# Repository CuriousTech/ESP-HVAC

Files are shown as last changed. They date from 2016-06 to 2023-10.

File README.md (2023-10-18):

# ESP-HVAC (ESP8266 & ESP-32)
WiFi Smart Omniscient HVAC Touchscreen Theromstat  

This project is discontinued (except for bugfixes and support code changes). New work will be on 
[WT32-SC01-HVAC](https://github.com/CuriousTech/WT32-SC01-HVAC)  

<b>2018 Model:</b> The new model was redesigned with a cooler switching regulator (~20mA idle, with a dim screen), smaller ($16.50 from OSHPark) more options for the temp/RH sensor, and the rotory encoder was removed, but has a header for an external encoder or buttons. The only difference in connections is the SCL/SDA were accidentaly reversed on the onboard SHTxx chip. Pics should be at the bottom.  

Notes about the Nextion: The baudrate is bauds=115200 in the main initialize varaibles. This will allow it to communicate at the highest speed.  

The "Basic" (Discovery model works without modification) has a 10K pullduown resistor for 5V tolerance (R13: next to the connector).  Removing this allows the ESP8266 to boot normally and operate without any resistors added, or add a 10K pullup between TX and 3V3 when serial debug is not connected.  I've opted for the removal of the resistor, which fixes all problems.  The 5K6 on the thermostat (R17) allowed it to operate with serial connected plus the pulldown, but not without.  The blue wire (data sent to the ESP) doesn't really need any resistors.  The ESP can't be programmed without a 1K while both are connected, and with the 1K and debug the touchscreen won't work.  So just disconnect the wire while programming and reconnect it after.  

This has replaced the old Spark-O-Stat with a newer system using the ESP-07 (now ESP32), with a better screen (Nextion HMI 2.8" touchscreen), 5 outputs (1 extra output for humidifier), option for SHT21 (I2C) or DHT22/11, AM2302/22, and anolog input for expansion.  

Main and remote units are designed into the single PCB with wired 5V or USB Mini-B for the remote units, and 24VAC for main.  Headers on top are for onboard serial programming of the ESP and Nextion.  Only power it with 1 source at a time. (3V3 for just the ESP, encoder, and temp sensor, 5V to include the display, or 24VAC for all of it including the SSRs). Add the switching regulator to the remote for battery power (6-40V).   

<b>Remote:</b> By tapping the target temperature on the display, it will toggle transmitting the remote temperature and humidity to the main unit to use in all operations.  Tapping the same item on the main unit will also end the remote temperature connection.  There are notifications to indicate use as well as a flashing run indicator instead of solid.  

Some screens including a keyboard and SSID chooser, but this is using the auto connect with SoftAP server (which attempts to find the stored SSID while waiting on input) so it should never be needed.  The dimmed screensaver will change to a clock, and a few other odd displays over time.  

Some display screenshots

Cool/heat low/high:  
These are the desired temperature ranges for cooling and heating, which are calculated based on outside temperature over the next set number of days.  

Cycle:  
Disable heat and cool, but still cycles the fan by the Auto Fan: Run: settings. 4:00 and 5 default = 5 minutes every 4 hours.  

Threshold:  
The temperature offset to complete a cycle.  

Pre-cycle fan time:  
0 disables, 1 second to 5 minutes.  This is the first phase of the cycle.  When the temperature reaches the target, the fan is turned on to cycle air for the set time, which causes the thermostat to read a more overall temperature. If the threshold is reached before this ends, which it can, it will shut off. Otherwise it continues to the run phase, which runs for at least the cycleMin period to save wear on the compressor because this does shorten the run time considerably.  A good value to use is the time it takes to lower the temperature after turning the fan on before it plateaus.  Usually around 2 minutes.  

Post-cycle fan time:  
Runs fan after cycle completes.  This is the third phase of the cycle, which continues to push air through the cold radiator and ductwork.  2 minutes is good, but you can use an IR thermometer on a vent to see how long the cold air continues.  

Humidifier settings:  
Off: Always off  
Fan: Run when fan is on  
Run: Run when thermostat is running a cycle  
Auto1: Operate by humidistat during run cycles  
Auto2: Humidistat runs indepentantly of thermostat (shares fan control)  

Override:  
Use to heat or cool by a selected offset temperature for a specified time.  

Freshen:  
Starts the fan with a timeout.  This uses the post fan timer, so a normal cycle will cancel it.  

Idle min, cycle min/max:  
These are timers in seconds to control the thermstat operating limits.  Idle min is the shortest time between cycles.  Cycle min is the shortest time for a cycle, and max is the longest.  Be careful with these settings.  Running the compressor too short or too long can cause damage.  

Away time and temperature delta offset:  
The away time is in hours:minutes unlike the rest of the timers, but uses the override timer.  It can be turned on and off with the button, but will also turn off with the timer.  There are 2 temp values that are displayed depending on heat or cool mode.  One for heat and one for cool, like the pre/post fan.
Like any setting, it can be automated with something like Tasker.  To turn on would be <b>http://ip:85?key=password&away=1</b>  

Other settings:  
AC differential limit: Increases thermostat if inside/outside difference is more than 30. This assumes Fahrenheit. Change for Celcius.  
Heat Threshold: Heatpump will switch off and use gas when outside temp goes below set value (default 33). Change for Celcius.  
PKW (price per killawatt hour), CFM (gas cubic feet per minute), CCF (cost per 100 cubic foot): Set the PPKW and CCF based on billing. CFM is dependant on the furnace.  
FC Shift (in minutes): Shifts the forecast for the temperature adjust. Use the setting on the chart page (they don't affect the actual settings) to determine what's best. There are 2 values for heat and cool here as well.   

remotepage  

The web chart.  Dark gray is off, cyan is fan running, blue is compressor+fan, NG is red, HP is yellow, rh is green, the target/threshold is the wave.  The thermostat is in the hottest room in the house, so it does look warmer than it really is, but that's why there's a remote unit, and now multiple sensors.  
chartpage  

dualstats  

New Model
model2  
Remote (this uses only a few components: the 3.3V regulator, 3 capacitors, USB connector, temp sensor, and 7 required resistors)  
model2rem  
model2side  

Sensor web page  
envmon

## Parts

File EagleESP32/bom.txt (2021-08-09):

PCB OSHPark $17.55 for 3

ESP-32        eBay
USB Micro-B   ZX62D-B-5PA8(30) or common eBay (remote only)
Nextion HMI   2.8" eBay
3V3R          MCP1755T-3302E/OT or MCP1802T-3302
TXRX,LCD      0.1" headers. Use for serial programming ESP, debug, Nextion.

rh/temp sensor options:
 AM2320      (larger 4 pin, i2c)
 AM2322      (lower 4 pin, i2c)
 SHT21       DFN-6
 Si7021      cheaper DFN-6
 Si7034      super cheap

R1-R5     *  0805 470 (390 lowest)
R7        *  0805 470
R8,R9        0805 10K
R10,R11      0805 4K7
R12          0805 10K (pullup in case 10K isn't removed from Nextion)
R13,R15      0805 1K
R14          0805 5K1

F1        *  1812 PPTC Fuse 1.5A PTS181224V150
BR        *  MDB6S
VREG      *  LMR16006YQ5DDCRQ1
L1        *  0805 6.8uH IFSC0806AZER6R8M01
D1,D2    (*) SOT-223 NSVR0320MW2T1G
C1 or C2  *  10uF+ 25V+ 5mm (25SEPF56M 56uF throughole)
C3-C6     *  0805 16V 0.1uF
C7        *  0805 16V 1uF
C8        *  0805 16V 10uF
C9           0603 16V 0.1uF (if SHTxx used)
C10       *  0805 2.2uF

Q1           PMV20ENR (for future speaker)
SPK          20mm-36mm 32 ohm speaker
K1-K5     *  G3VM-61GR2
X1        *  39357-0008 (or 691322110008 and 691361100008) Screw terimal, 8 position 3.5mm pitch
Button       TL1014BF160QG

* Only for main controller

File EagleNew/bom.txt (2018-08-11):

PCB OSHPark $16.50 for 3

ESP-07          eBay
USB Micro-B     ZX62D-B-5PA8(30) or common eBay (remote only)
Nextion HMI     2.8" eBay
3V3R            MCP1755T-3302E/OT
TXRX,LCD,DHT    0.1" headers. Use for serial programming ESP, debug, Nextion.

rh/temp sensor options:
 AM2302/DHT22   (upper 4 pin)
 AM2320         (lower 4 pin, i2c)
 SHT21          DFN-6
 Si7021         cheaper DFN-6
 Si7034         super cheap

R1-R5       *   0805 470
R6-R8       *   0805 10K
R9              0805 10K (use R9 on remote as well)
R10,R11         0805 10K
R12,R13         0805 4K7 (ignore for AM2302)
R14,R15         ADC voltage divider (not used)
R16,R17         0805 5K6
R19             0805 10K (pullup in case 10K isn't removed from Nextion)
R20         *   0805 4K7

F1          *   1812 PPTC Fuse 1.5A PTS181224V150
BR          *   MDB10SV
VREG        *   LMR16006YQ5DDCRQ1
L1          *   0805 6.8uH IFSC0806AZER6R8M01
D1          *   SOT-223 NSVR0320MW2T1G
C1 or C2    *   10uF+ 25V+ 5mm (PCV1E470MCL2GS 6mm) or UZR1V100MCL1GB
C3-C6       *   0805 16V 0.1uF
C7          *   0805 16V 1uF
C8          *   0805 16V 10uF
C9              0603 16V 0.1uF (if SHTxx used)
C10         *   0805 2.2uF

K1-K5       *   G3VM-61GR2 (stays cooler), or AQY282S, or any SMD-DIP4 1FormA 30VAC+ 500mA~5A
X1          *   39357-0008 (or 691322110008 and 691361100008) Screw terimal, 8 position 3.5mm pitch
J1              ADC expansion (Not used)

* Only for main controller

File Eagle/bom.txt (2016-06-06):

ESP-07          eBay
USB Mini-B      Only use for powering remote unit with wall adapter
Nextion HMI     2.8" eBay
AM2302/DHT22    Don't use with SHT21
SHT21           Don't use with DHT22
R1-R5       *   0805 470
R6-R9       *   0805 10K (do not remove R9 - GPIO15 must be low on boot)
R10,R11         0805 10K
R12,R13         0805 4K7
R14,R15         ADC voltage divider (not used)
R16,R17         5K6
R18             0 jumper (Do not use: Allows for I2C device in place of DHT22)
R19             10K 0805 (pullup in case 10K isn't removed from Nextion)
R20         *   4K7 0805
C1          *   UWD1V150MCL1 35V 15uF
C2          *   UCL1A221MCL1GS 10V 220uF
C3,C4           0805 16V 0.1uF
C5,C6           0805 10V 0.01uF
C7,C8           0805 16V 1uF
C9              0805 16V 0.1uF
F1          *   1812 PPTC Fuse 1.5A PTS181224V150
LCD,NEXPROG     4-pin 0.1" header.  Same pinout.  Use either for serial programming of display.
J1              ADC expansion.  Not used.
PIC10F      *   Not used.  Watchdog connected to SCL for monitor, RESET output.
5VSWPP      *   MIC4680-5.0YM
3V3R            MCP1755T-3302E/OT
L1          *   SRU1048-680Y
K1-K5       *   AQY282SZ or AQY282S (3 main, 1 for HP, 1 for humidifier)
B1          *   DF206S-G
D1          *   B260A-13-F
X1          *   39357-0008 Screw terimal, 8 position 3.5mm pitch
Encoder         EC12E24204A2 or other 12mm short shaft
Q1          *   MMBT2907ALT1G (general purpose BJT PNP) GPIO0 must be high or Z on boot.
PRG,TXRX        2-pin headers.  Use for serial programming ESP, debug, Nextion simulator.

* Only for main controller

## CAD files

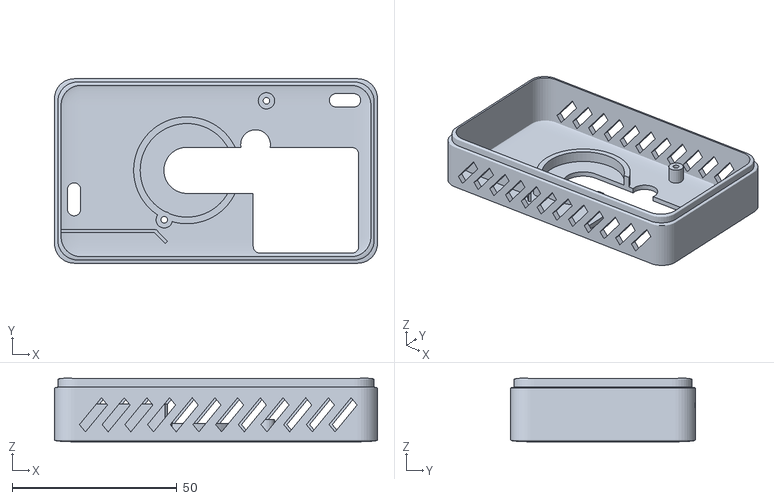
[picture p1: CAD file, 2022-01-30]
3D/ThermostatBack_SHT21.stl
98.0 x 56.0 x 19.3

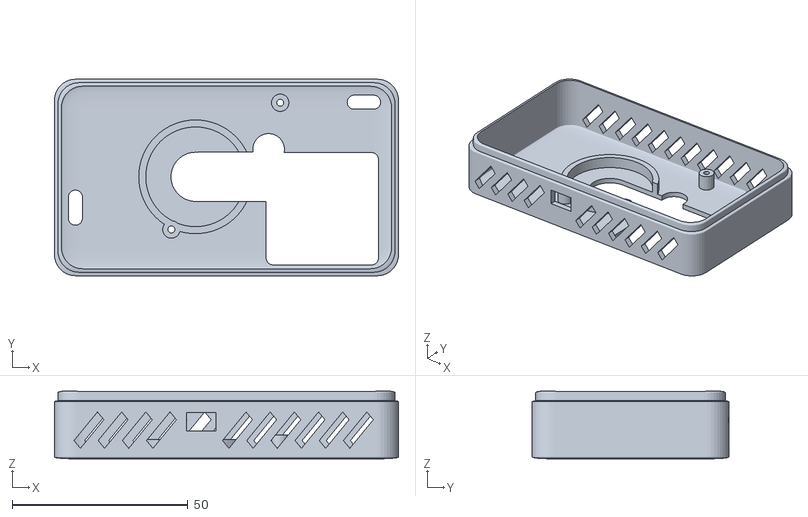
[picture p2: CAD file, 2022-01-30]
3D/ThermostatBack_AM2322.stl
98.0 x 56.0 x 19.3

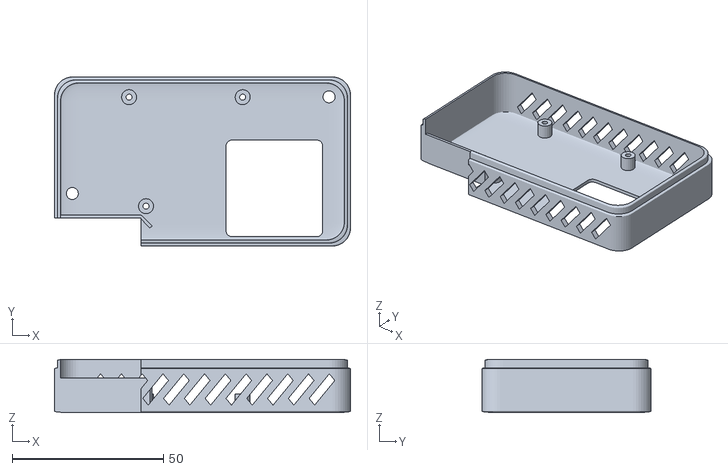
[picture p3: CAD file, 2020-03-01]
3D/BackM2.stl
98.0 x 56.0 x 17.6

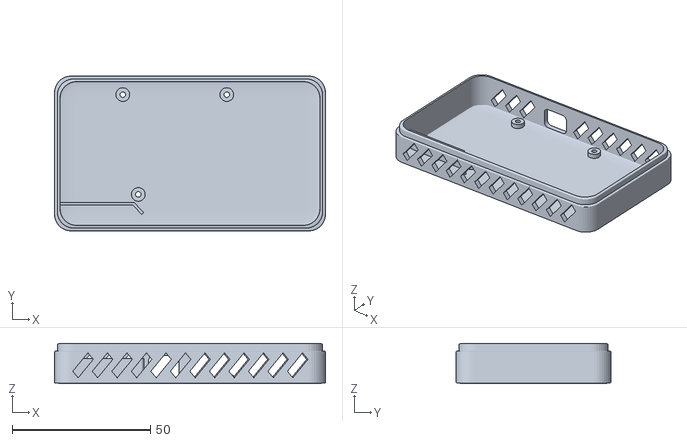
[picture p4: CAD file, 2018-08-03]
3D/RmtBackM2.stl
98.0 x 56.0 x 14.5

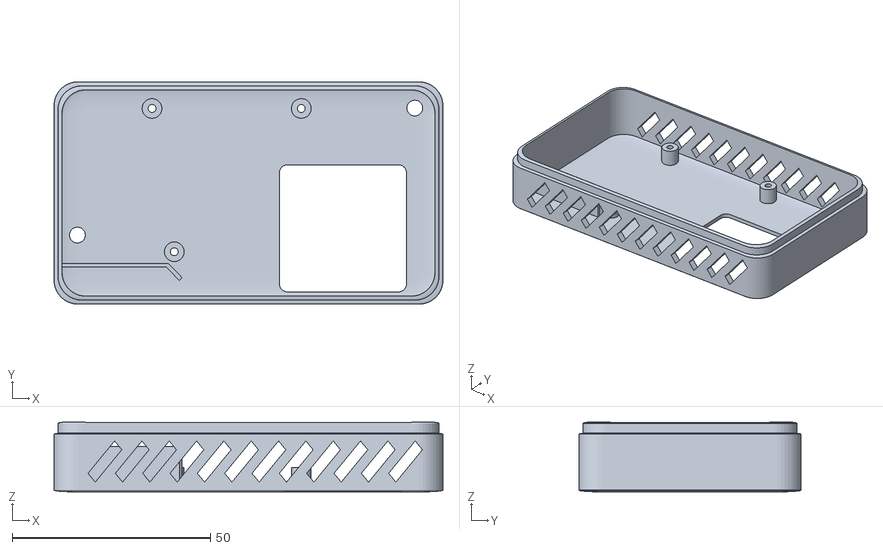
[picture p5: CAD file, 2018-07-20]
3D/BackDeepM2.stl
98.0 x 56.0 x 17.6

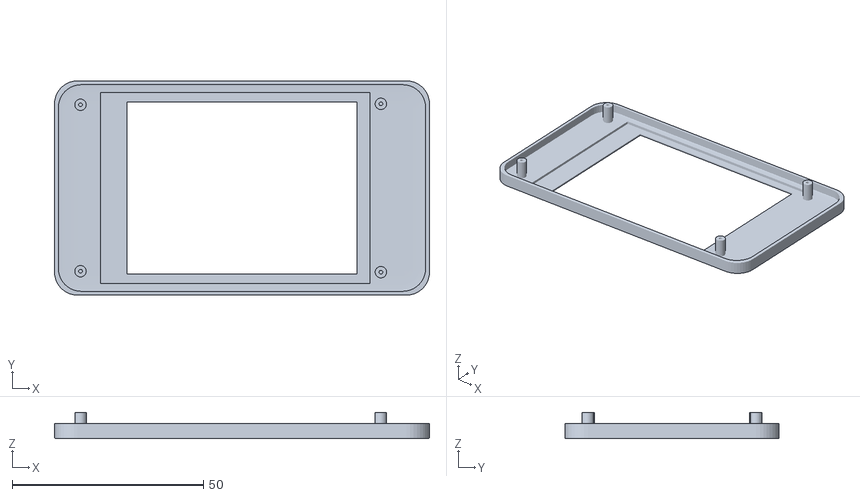
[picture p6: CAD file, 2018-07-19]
3D/FaceplateM2.stl
98.0 x 56.0 x 6.86

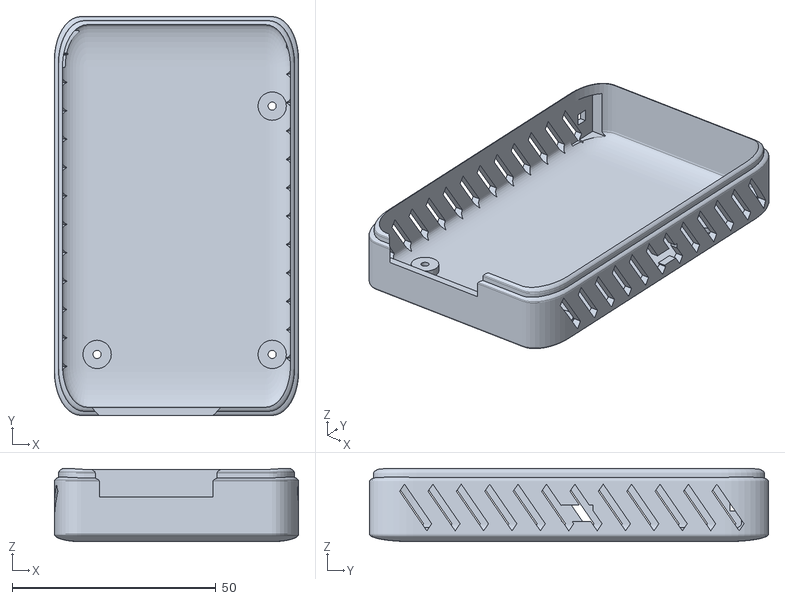
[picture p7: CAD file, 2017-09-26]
3D/Remote back.stl
60.0 x 98.0 x 18.0

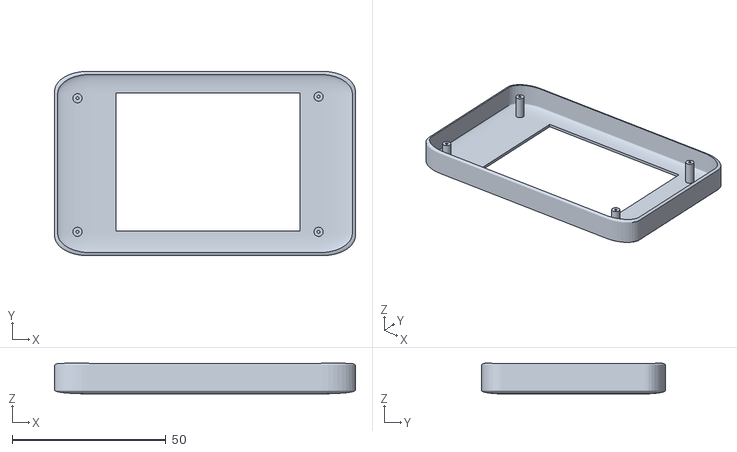
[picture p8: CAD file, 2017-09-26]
3D/Faceplate.stl
98.0 x 60.0 x 9.99

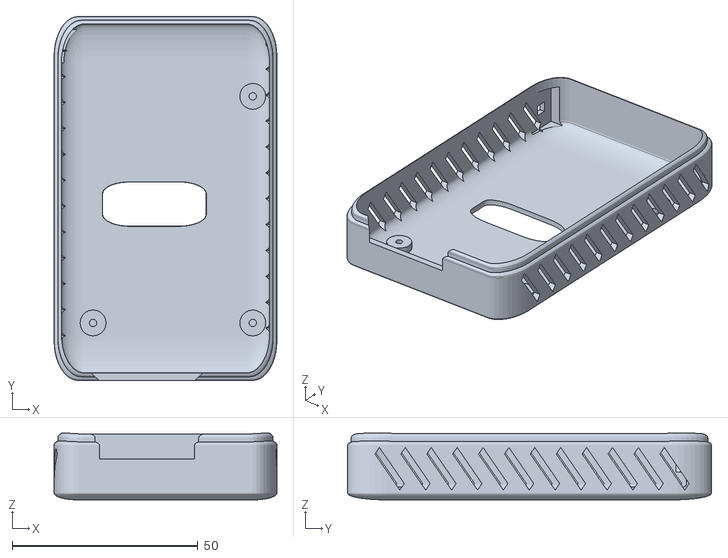
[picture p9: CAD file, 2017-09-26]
3D/Thermostat back.stl
60.0 x 98.0 x 18.0

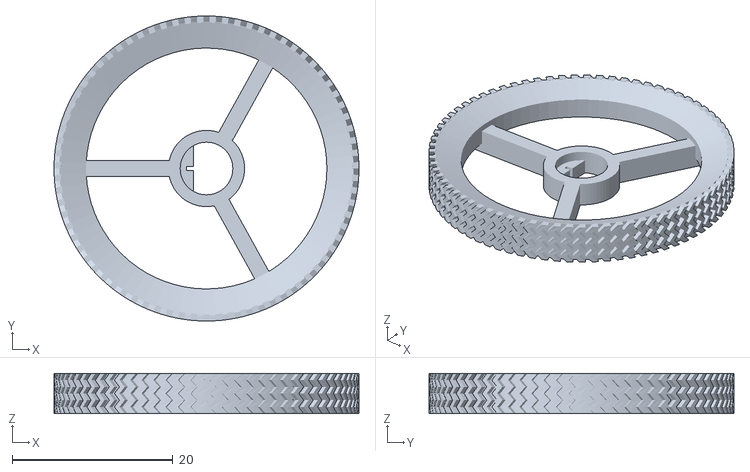
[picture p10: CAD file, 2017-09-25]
3D/Encoder Wheel.stl
38.0 x 38.0 x 5.00

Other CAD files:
3D/ThermostatBack_AM2302.stl
3D/ThermostatBack_AM2320.stl

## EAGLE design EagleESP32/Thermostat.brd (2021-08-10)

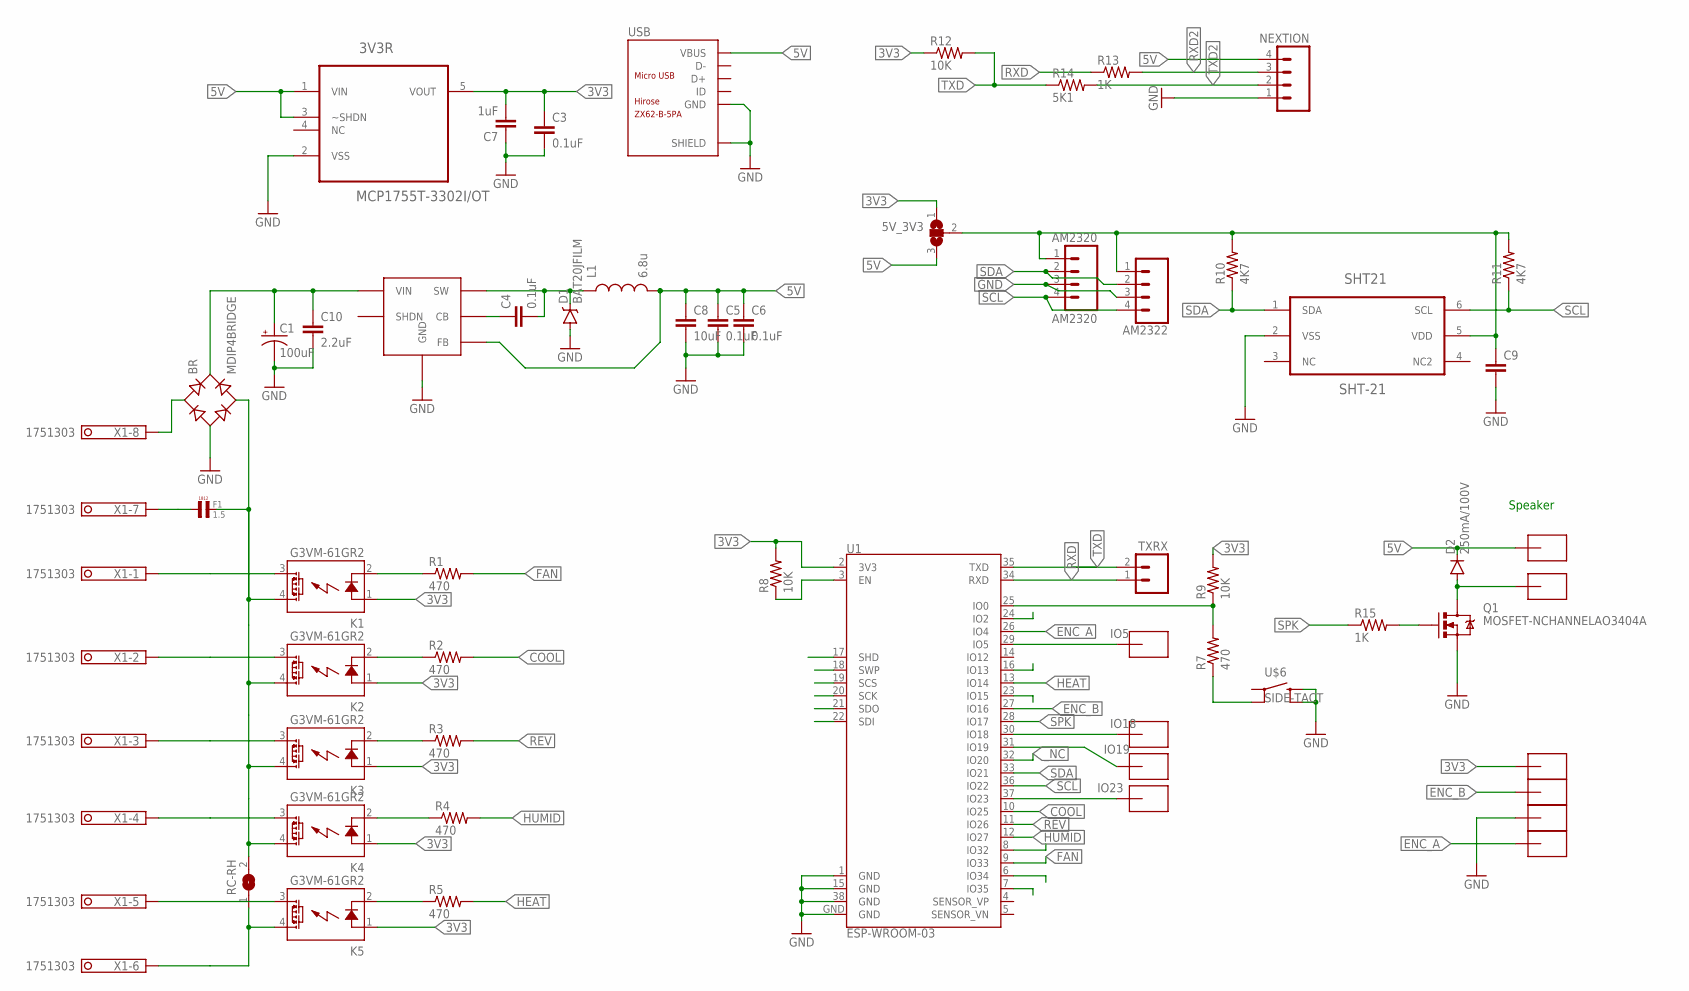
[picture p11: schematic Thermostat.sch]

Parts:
3V3R: MCP1755T-3302I/OT; SOT95P270X145-5N
5V_3V3: SJ2W; SJ_2
AM2320: AM2320; 1X04
AM2322: CONN_041.27MM; 1X04_1.27MM
BR: MDIP4BRIDGE; MICRODIP4
C1: 100uF; PANASONIC_C
C3, C4, C5, C6: 0.1uF; 0805
C7: 1uF; 0805
C8: 10uF; 0805
C9: CAP0603-CAP; 0603-CAP
C10: 2.2uF; 0805
D1: BAT20JFILM; SOD-323
D2: 250mA/100V; SOD-323
F1: 1.5; L4,8
K1, K2, K3, K4, K5: G3VM-61GR2; SOP04
L1: 6.8u; 1007
NEXTION: M04PTH; 1X04
Q1: MOSFET-NCHANNELAO3404A; SOT23-3
R1, R2, R3, R4, R5, R7: 470; 0805
R8, R9, R12: 10K; 0805
R10, R11: 4K7; 0805
R13, R15: 1K; 0805
R14: 5K1; 0805
RC-RH: SJ
SHT21: SHT-21; SHT21
TXRX: M02PTH; 1X02
U1: ESP-WROOM-03
U$1, U$2, U$3, U$4: SMD-PAD182X64; SMD-PAD1
U$5, U$7, U$8, U$9, U$10, U$11: SMD-PAD1SMD-PAD80X32; SMD-PAD6
U$6: SIDE-TACT
USB: ZX62-B-5PA; MICRO-USB5+6P-SMD-0.65-AB
VREG: LMR16006YQ; SOT-23-6
X1: 1751303

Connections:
3V3: 3V3R.5 (VOUT), 5V_3V3.1, C3.1, C7.2, K1.1 (A), K2.1 (A), K3.1 (A), K4.1 (A), K5.1 (A), R8.2, R9.2, R12.1, U1.2 (3V3), U$7.>PAD
5V: 3V3R.1 (VIN), 3V3R.3 (~SHDN), 5V_3V3.3, C5.1, C6.1, C8.1, D2.C, L1.2, NEXTION.4, U$5.>PAD, USB.1 (VBUS), VREG.3 (FB)
COOL: R2.2, U1.10 (IO25)
ENC_A: U1.26 (IO4), U$10.>PAD
ENC_B: U1.27 (IO16), U$8.>PAD
FAN: R1.2, U1.9 (IO33)
GND: 3V3R.2 (VSS), AM2320.3, AM2322.3, BR.-, C1.-, C3.2, C5.2, C6.2, C7.1, C8.2, C9.2, C10.2, D1.A, NEXTION.1, Q1.2 (S), SHT21.2 (VSS), U1.1 (GND), U1.15 (GND), U1.38 (GND), U1.GND, U$6.3 (2), U$6.4, U$9.>PAD, USB.5 (GND), USB.P1 (SHIELD), USB.P2 (SHIELD), USB.P3 (SHIELD), USB.P4 (SHIELD), USB.P5 (SHIELD), USB.P6 (SHIELD), VREG.2 (GND)
HEAT: R5.2, U1.13 (IO14)
HUMID: R4.2, U1.12 (IO27)
IO5: U1.29 (IO5), U$3.>PAD
IO18: U1.30 (IO18), U$4.>PAD
IO19: U1.31 (IO19), U$1.>PAD
IO23: U1.37 (IO23), U$2.>PAD
unnamed: C4.2, D1.C, L1.1, VREG.6 (SW)
unnamed: BR.AC2, F1.P$2 (2), K1.4 (DS1), K2.4 (DS1), K3.4 (DS1), K4.4 (DS1), RC-RH.2
unnamed: K4.2 (K), R4.1
unnamed: Q1.1 (G), R15.2
unnamed: K3.2 (K), R3.1
unnamed: R8.1, U1.3 (EN)
unnamed: K2.2 (K), R2.1
unnamed: K4.3 (DS2), X1.4
unnamed: K2.3 (DS2), X1.2
unnamed: R7.2, R9.1, U1.25 (IO0)
unnamed: K1.3 (DS2), X1.1
unnamed: K1.2 (K), R1.1
unnamed: C4.1, VREG.1 (CB)
unnamed: K5.3 (DS2), X1.5
unnamed: BR.AC1, X1.8
unnamed: K5.4 (DS1), RC-RH.1, X1.6
unnamed: F1.P$1 (1), X1.7
unnamed: BR.+, C1.+, C10.1, VREG.5 (VIN)
unnamed: K5.2 (K), R5.1
unnamed: R7.1, U$6.2 (3)
unnamed: K3.3 (DS2), X1.3
unnamed: D2.A, Q1.3 (D), U$11.>PAD
NC: SHT21.3 (NC)
PWR: 5V_3V3.2, AM2320.1, AM2322.1, C9.1, R10.2, R11.2, SHT21.5 (VDD)
REV: R3.2, U1.11 (IO26)
RXD: R13.1, TXRX.1, U1.34 (RXD)
RXD2: NEXTION.3, R13.2
SCL: AM2320.4, AM2322.4, R11.1, SHT21.6 (SCL), U1.36 (IO22)
SDA: AM2320.2, AM2322.2, R10.1, SHT21.1 (SDA), U1.33 (IO21)
SPK: R15.1, U1.28 (IO17)
TXD: R12.2, R14.1, TXRX.2, U1.35 (TXD)
TXD2: NEXTION.2, R14.2
_NC: U1.32 (IO20)

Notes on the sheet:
Speaker

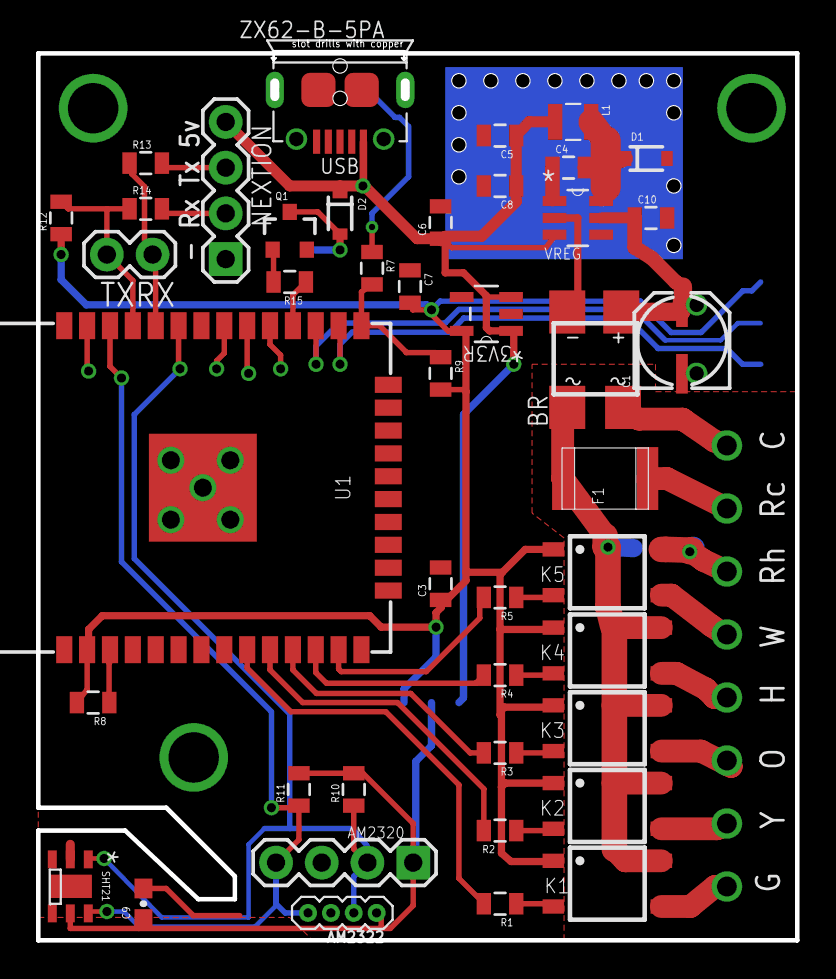
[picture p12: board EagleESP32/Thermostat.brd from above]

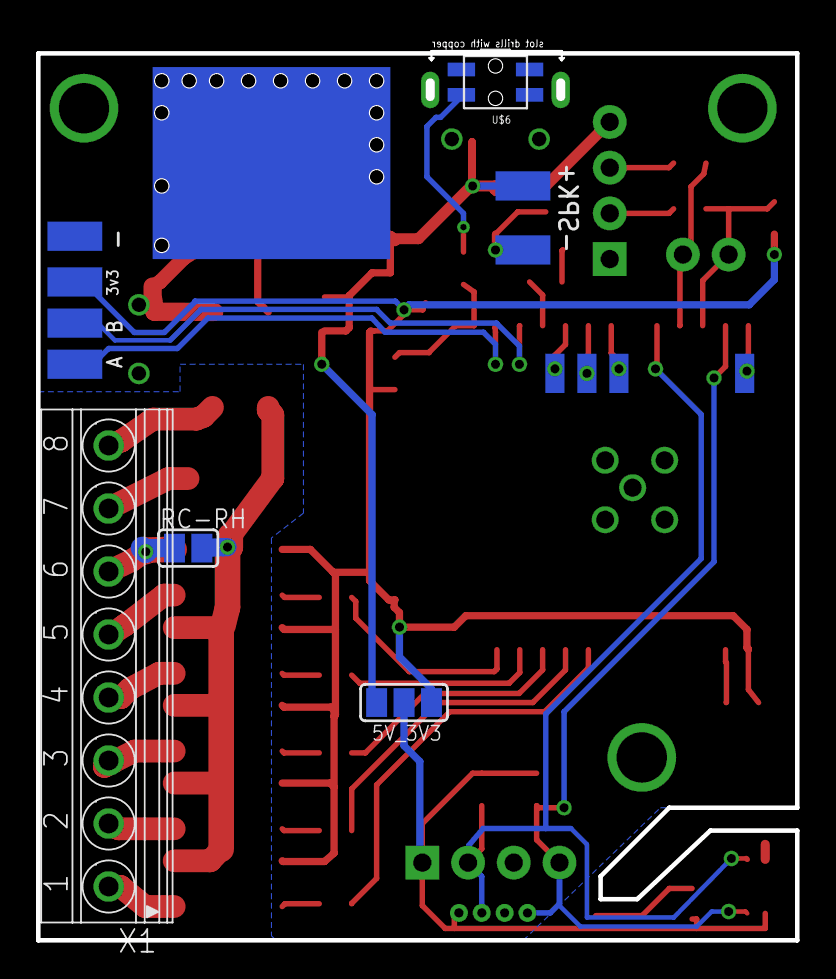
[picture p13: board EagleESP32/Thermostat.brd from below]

Board: 2 copper layers, 42.2 x 49.3 mm, 57 parts (14 on the bottom side), 44 nets.

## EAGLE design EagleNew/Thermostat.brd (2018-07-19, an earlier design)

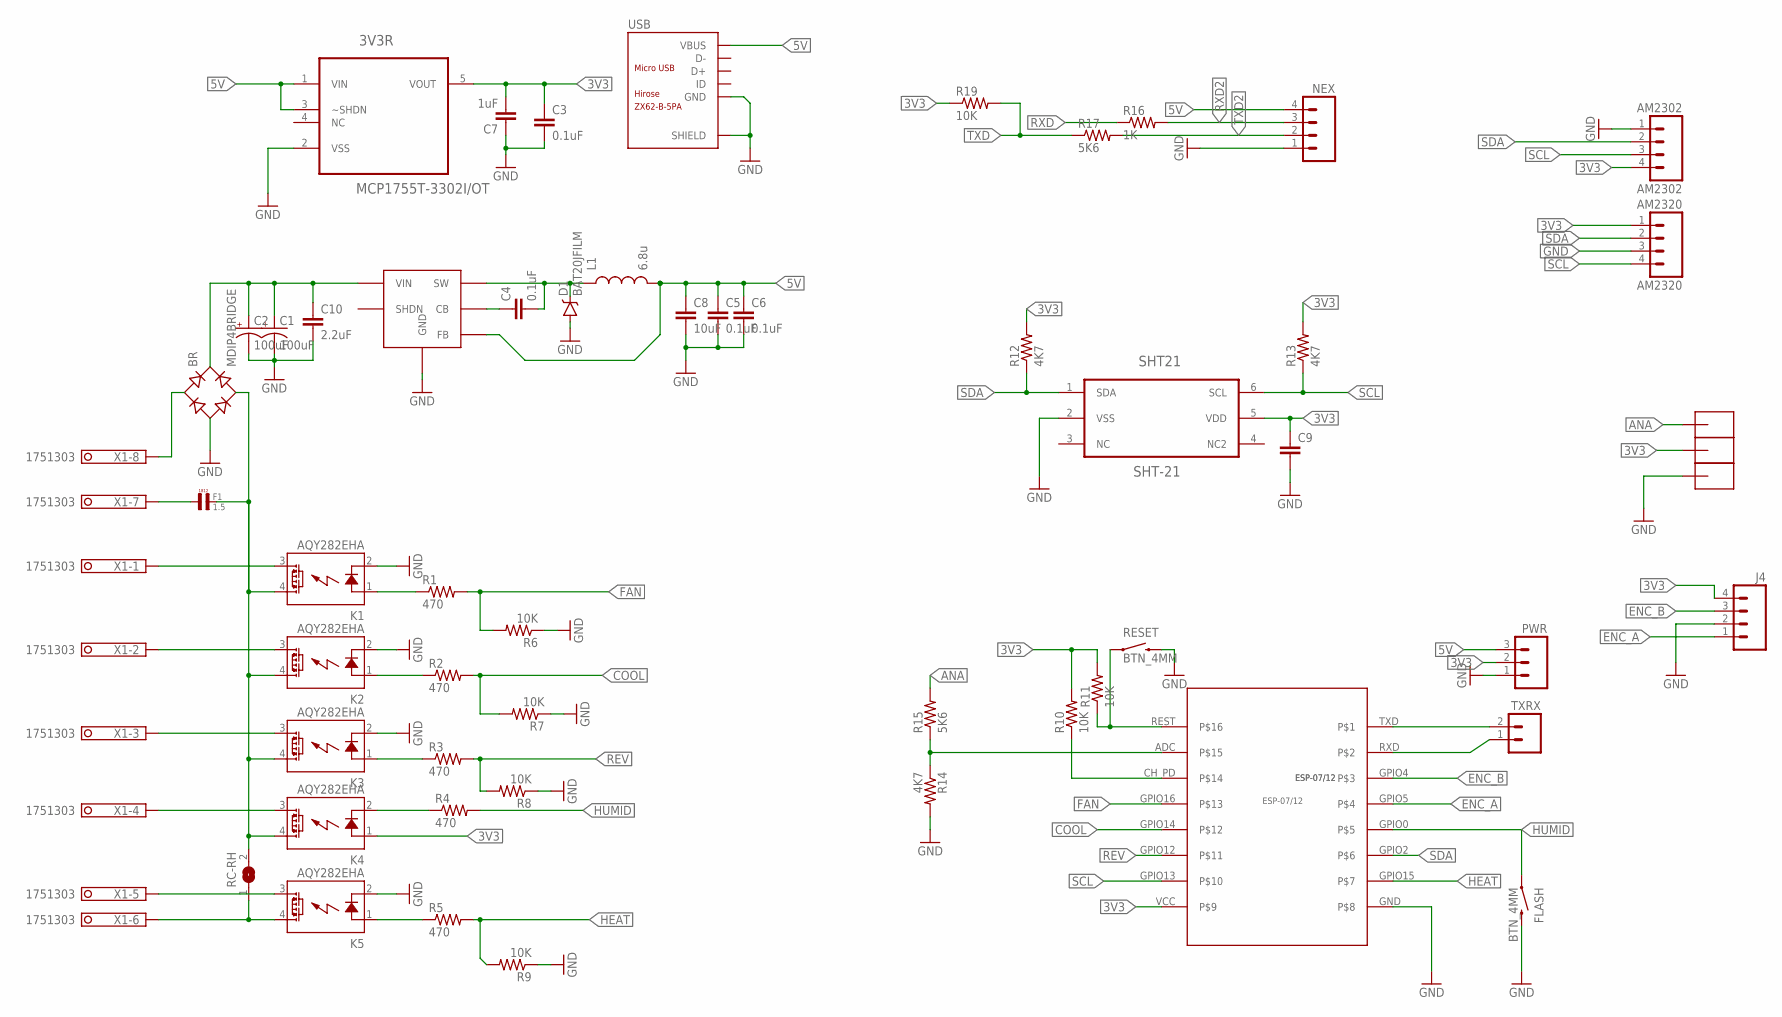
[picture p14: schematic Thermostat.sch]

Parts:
3V3R: MCP1755T-3302I/OT; SOT95P270X145-5N
AM2302: AM2302; 1X04
AM2320: AM2320; 1X04
BR: MDIP4BRIDGE; MICRODIP4
C1, C2: 100uF; PANASONIC_C
C3, C4, C5, C6: 0.1uF; 0805
C7: 1uF; 0805
C8: 10uF; 0805
C9: CAP0603-CAP; 0603-CAP
C10: 2.2uF; 0805
D1: BAT20JFILM; SOD-323
F1: 1.5; L4,8
FLASH: BTN_4MM
J4: M04PTH; 1X04
K1, K2, K3, K4, K5: AQY282EHA; SOP04
L1: 6.8u; 1007
NEX: M04PTH; 1X04
PWR: M03PTH; 1X03
R1, R2, R3, R4, R5: 470; 0805
R6, R7, R8, R9, R10, R11, R19: 10K; 0805
R12, R13, R14: 4K7; 0805
R15, R17: 5K6; 0805
R16: 1K; 0805
RC-RH: SJ
RESET: BTN_4MM
SHT21: SHT-21; SHT21
TXRX: M02PTH; 1X02
U$1: ESP-07/12
U$2, U$3, U$4: SMD-PAD182X64; SMD-PAD1
USB: ZX62-B-5PA; MICRO-USB5+6P-SMD-0.65-AB
VREG: LMR16006YQ; SOT-23-6
X1: 1751303

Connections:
3V3: 3V3R.5 (VOUT), AM2302.4, AM2320.1, C3.1, C7.2, C9.1, J4.4, K4.1 (A), PWR.2, R10.2, R11.2, R12.2, R13.2, R19.1, SHT21.5 (VDD), U$1.VCC, U$3.>PAD
5V: 3V3R.1 (VIN), 3V3R.3 (~SHDN), C5.1, C6.1, C8.1, L1.2, NEX.4, PWR.3, USB.1 (VBUS), VREG.3 (FB)
ADC: R14.1, R15.1, U$1.ADC
ANA: R15.2, U$4.>PAD
COOL: R2.2, R7.2, U$1.GPIO14
ENC_A: J4.1, U$1.GPIO5
ENC_B: J4.3, U$1.GPIO4
FAN: R1.2, R6.2, U$1.GPIO16
GND: 3V3R.2 (VSS), AM2302.1, AM2320.3, BR.-, C1.-, C2.-, C3.2, C5.2, C6.2, C7.1, C8.2, C9.2, C10.2, D1.A, FLASH.2, J4.2, K1.2 (K), K2.2 (K), K3.2 (K), K5.2 (K), NEX.1, PWR.1, R6.1, R7.1, R8.1, R9.1, R14.2, RESET.2, SHT21.2 (VSS), U$1.GND, U$2.>PAD, USB.5 (GND), USB.P1 (SHIELD), USB.P2 (SHIELD), USB.P3 (SHIELD), USB.P4 (SHIELD), USB.P5 (SHIELD), USB.P6 (SHIELD), VREG.2 (GND)
HEAT: R5.2, R9.2, U$1.GPIO15
HUMID: FLASH.1, R4.2, U$1.GPIO0
unnamed: K4.2 (K), R4.1
unnamed: C4.2, D1.C, L1.1, VREG.6 (SW)
unnamed: BR.AC2, F1.P$2 (2), K1.4 (DS1), K2.4 (DS1), K3.4 (DS1), K4.4 (DS1), RC-RH.2
unnamed: K1.1 (A), R1.1
unnamed: K2.1 (A), R2.1
unnamed: K3.1 (A), R3.1
unnamed: K4.3 (DS2), X1.4
unnamed: K2.3 (DS2), X1.2
unnamed: K1.3 (DS2), X1.1
unnamed: C4.1, VREG.1 (CB)
unnamed: K5.3 (DS2), X1.5
unnamed: BR.AC1, X1.8
unnamed: K5.4 (DS1), RC-RH.1, X1.6
unnamed: F1.P$1 (1), X1.7
unnamed: BR.+, C1.+, C2.+, C10.1, VREG.5 (VIN)
unnamed: K5.1 (A), R5.1
unnamed: K3.3 (DS2), X1.3
unnamed: R10.1, U$1.CH_PD
NC: SHT21.3 (NC)
REST: R11.1, RESET.1, U$1.REST
REV: R3.2, R8.2, U$1.GPIO12
RXD: R16.1, TXRX.1, U$1.RXD
RXD2: NEX.3, R16.2
SCL: AM2302.3, AM2320.4, R13.1, SHT21.6 (SCL), U$1.GPIO13
SDA: AM2302.2, AM2320.2, R12.1, SHT21.1 (SDA), U$1.GPIO2
TXD: R17.1, R19.2, TXRX.2, U$1.TXD
TXD2: NEX.2, R17.2

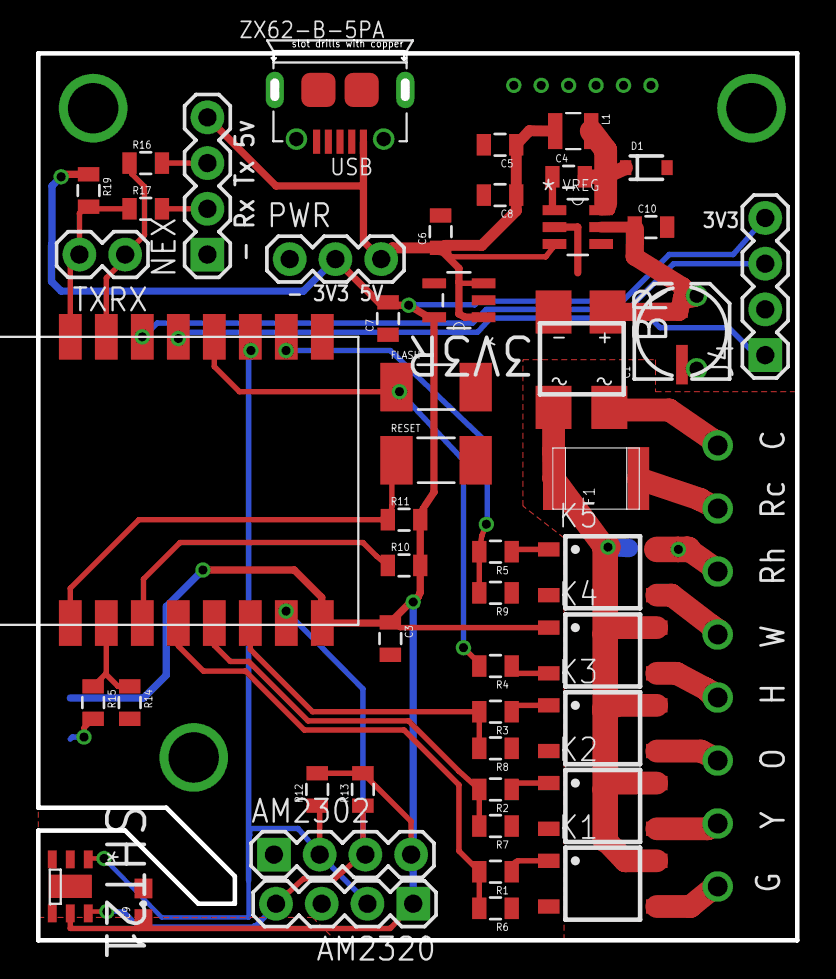
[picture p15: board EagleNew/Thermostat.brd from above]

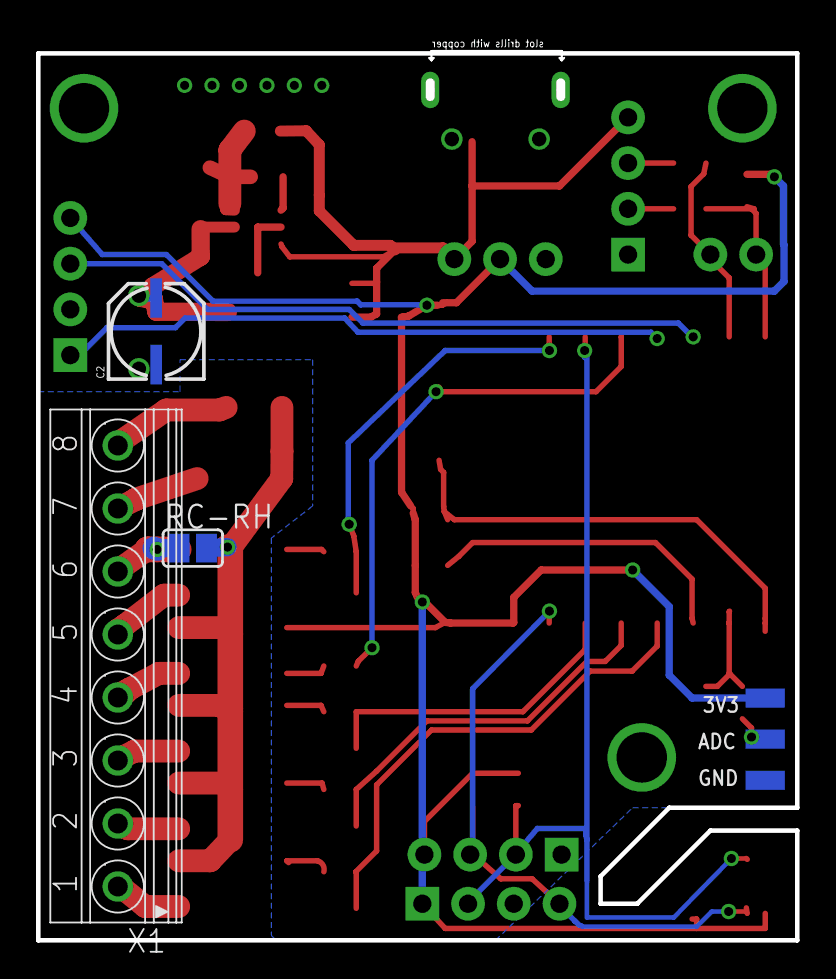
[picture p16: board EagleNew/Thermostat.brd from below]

Board: 2 copper layers, 42.2 x 49.3 mm, 55 parts (6 on the bottom side), 37 nets.

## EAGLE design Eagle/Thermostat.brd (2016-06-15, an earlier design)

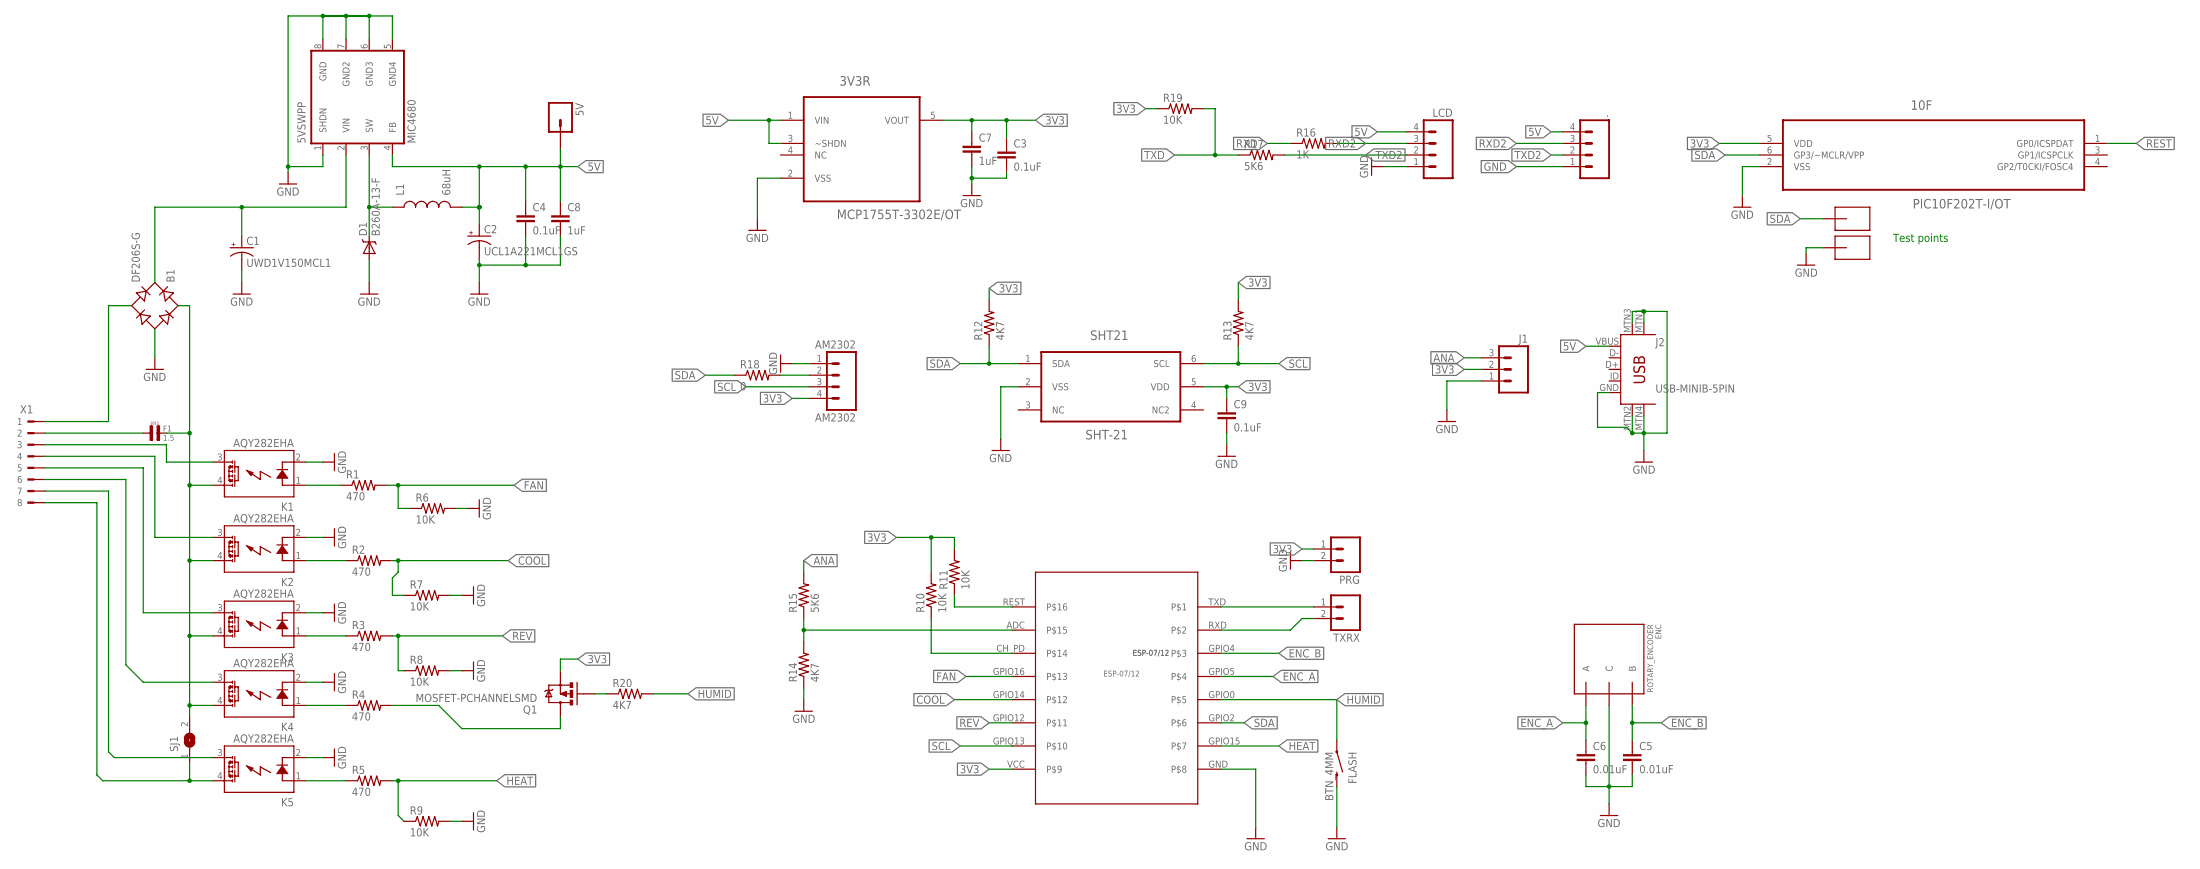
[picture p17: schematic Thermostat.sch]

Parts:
3V3R: MCP1755T-3302E/OT; SOT95P270X145-5N
5V: M01PTH; 1X01
5VSWPP: MIC4680; SO08
10F: PIC10F202T-I/OT; SOT95P270X145-6N
.: M04PTH; 1X04
AM2302: AM2302; 1X04
B1: DF206S-G; DFS
C1: UWD1V150MCL1; PANASONIC_C
C2: UCL1A221MCL1GS; PANASONIC_D
C3, C4, C9: 0.1uF; 0805
C5, C6: 0.01uF; 0805
C7, C8: 1uF; 0805
D1: B260A-13-F; SMA-DIODE
ENC: ROTARY_ENCODER; ROTORY_ENC
F1: 1.5; L4,8
FLASH: BTN_4MM
J1: M03PTH; 1X03
J2: USB-MINIB-5PIN; USB-MINIB
K1, K2, K3, K4, K5: AQY282EHA; SOP04
L1: 68uH; DR1030
LCD: M04PTH; 1X04
PRG: M02PTH; 1X02
Q1: MOSFET-PCHANNELSMD; SOT23-3
R1, R2, R3, R4, R5: 470; 0805
R6, R7, R8, R9, R10, R11, R19: 10K; 0805
R12, R13, R14, R20: 4K7; 0805
R15, R17: 5K6; 0805
R16: 1K; 0805
R18: 0; 0805
SHT21: SHT-21; SHT21
SJ1: SJ
TXRX: M02PTH; 1X02
U$1: ESP-07/12
U$2, U$5: SMD-PAD1
X1: 180-8

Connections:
3V3: 3V3R.5 (VOUT), 10F.5 (VDD), AM2302.4, C3.1, C7.1, C9.1, J1.2, PRG.1, Q1.2 (S), R10.2, R11.2, R12.2, R13.2, R19.1, SHT21.5 (VDD), U$1.VCC
5V: 3V3R.1 (VIN), 3V3R.3 (~SHDN), 5V.1, 5VSWPP.4 (FB), ..4, C2.+, C4.1, C8.1, J2.VBUS, L1.2, LCD.4
ADC: R14.2, R15.1, U$1.ADC
ANA: J1.3, R15.2
COOL: R2.2, R7.1, U$1.GPIO14
ENC_A: C6.1, ENC.A, U$1.GPIO5
ENC_B: C5.1, ENC.B, U$1.GPIO4
FAN: R1.2, R6.1, U$1.GPIO16
GND: 3V3R.2 (VSS), 5VSWPP.1 (SHDN), 5VSWPP.5 (GND4), 5VSWPP.6 (GND3), 5VSWPP.7 (GND2), 5VSWPP.8 (GND), 10F.2 (VSS), ..1, AM2302.1, B1.-, C1.-, C2.-, C3.2, C4.2, C5.2, C6.2, C7.2, C8.2, C9.2, D1.A, ENC.C, FLASH.2, J1.1, J2.GND, J2.MTN1 (MTN2), J2.MTN2 (MTN3), J2.MTN3 (MTN1), J2.MTN4, K1.2 (K), K2.2 (K), K3.2 (K), K4.2 (K), K5.2 (K), LCD.1, PRG.2, R6.2, R7.2, R8.2, R9.2, R14.1, SHT21.2 (VSS), U$1.GND, U$2.>NAME
HEAT: R5.2, R9.1, U$1.GPIO15
HUMID: FLASH.1, R20.2, U$1.GPIO0
unnamed: Q1.1 (G), R20.1
unnamed: 5VSWPP.3 (SW), D1.C, L1.1
unnamed: B1.AC1, F1.P$2 (2), K1.4 (DS1), K2.4 (DS1), K3.4 (DS1), K4.4 (DS1), SJ1.2
unnamed: K1.1 (A), R1.1
unnamed: K2.1 (A), R2.1
unnamed: Q1.3 (D), R4.2
unnamed: K3.1 (A), R3.1
unnamed: K4.3 (DS2), X1.6
unnamed: K2.3 (DS2), X1.4
unnamed: K4.1 (A), R4.1
unnamed: K1.3 (DS2), X1.3
unnamed: AM2302.2, R18.2
unnamed: K5.3 (DS2), X1.7
unnamed: B1.AC2, X1.1
unnamed: 5VSWPP.2 (VIN), B1.+, C1.+
unnamed: K5.1 (A), R5.1
unnamed: K5.4 (DS1), SJ1.1, X1.8
unnamed: K3.3 (DS2), X1.5
unnamed: R10.1, U$1.CH_PD
unnamed: F1.P$1 (1), X1.2
NC: SHT21.3 (NC)
REST: 10F.1 (GP0/ICSPDAT), R11.1, U$1.REST
REV: R3.2, R8.1, U$1.GPIO12
RXD: R16.1, TXRX.2, U$1.RXD
RXD2: ..3, LCD.3, R16.2
SCL: AM2302.3, R13.1, SHT21.6 (SCL), U$1.GPIO13
SDA: 10F.6 (GP3/~MCLR/VPP), R12.1, R18.1, SHT21.1 (SDA), U$1.GPIO2, U$5.>NAME
TXD: R17.1, R19.2, TXRX.1, U$1.TXD
TXD2: ..2, LCD.2, R17.2

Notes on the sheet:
Test points

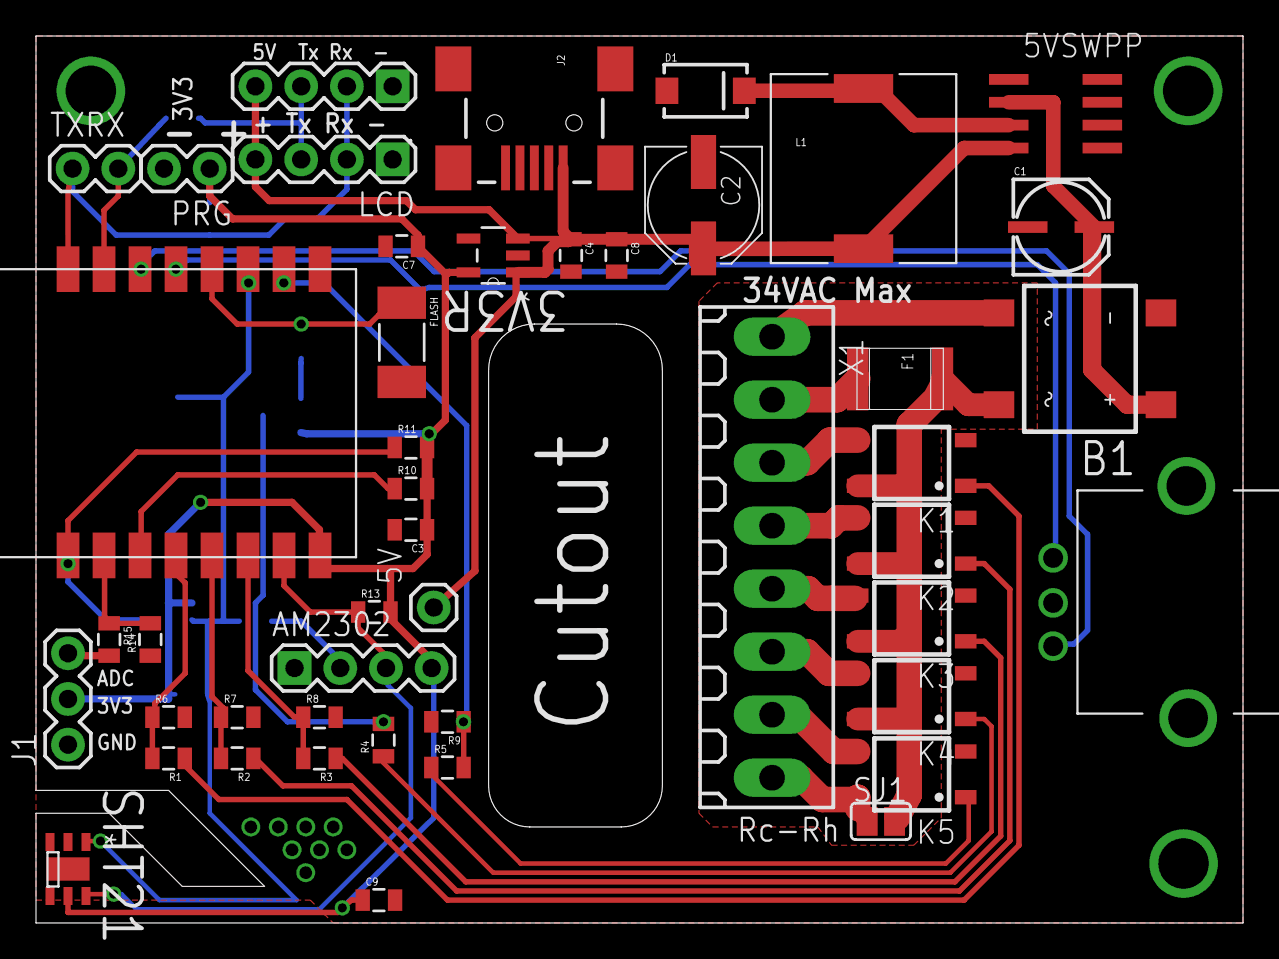
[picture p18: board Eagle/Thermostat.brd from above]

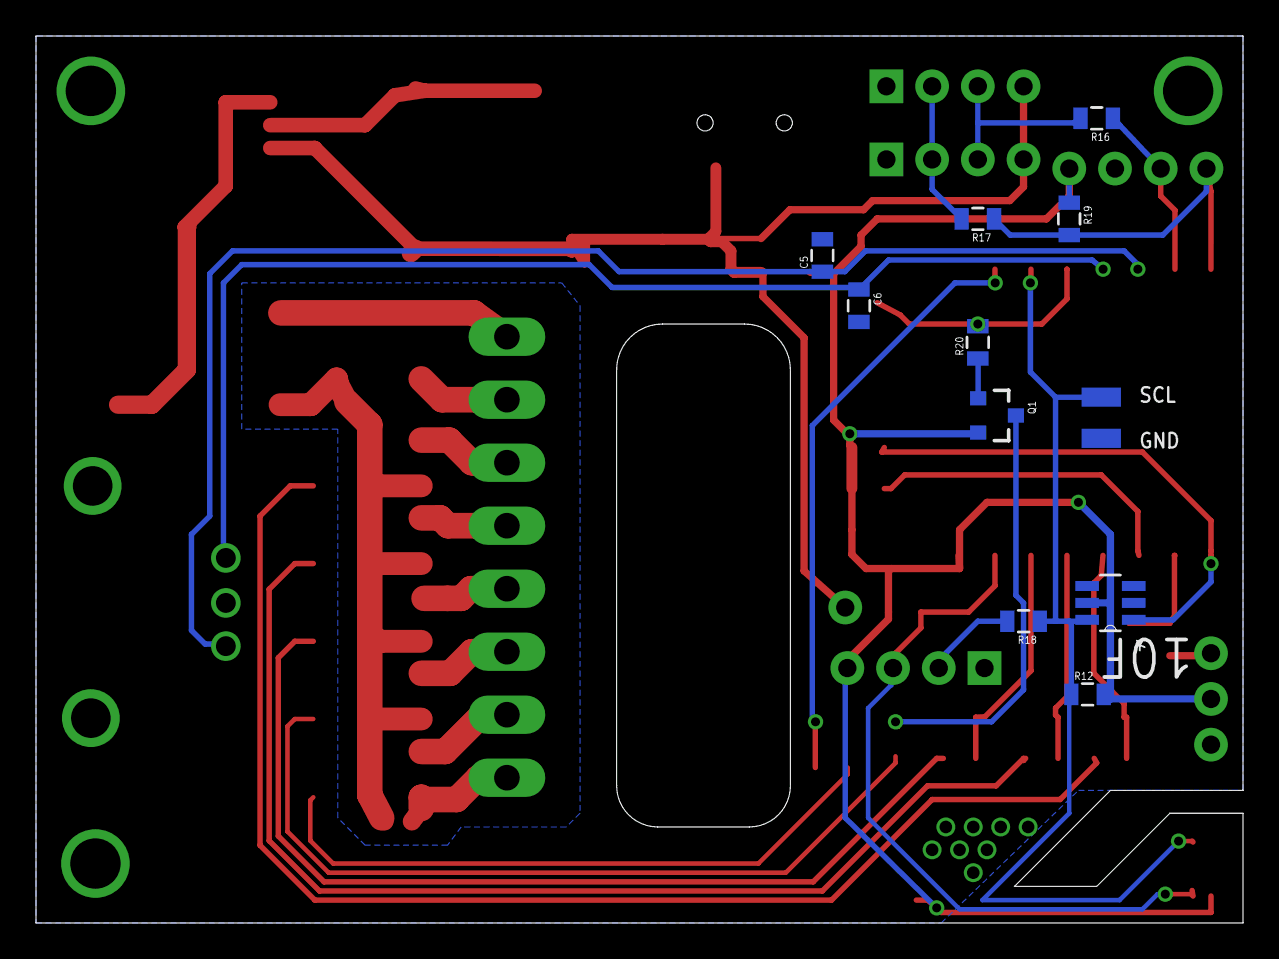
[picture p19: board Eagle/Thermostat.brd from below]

Board: 2 copper layers, 67.1 x 49.3 mm, 58 parts (12 on the bottom side), 39 nets.

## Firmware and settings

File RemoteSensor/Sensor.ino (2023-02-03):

/**The MIT License (MIT)

Copyright (c) 2016 by Greg Cunningham, CuriousTech

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
THE SOFTWARE IS PROVIDED "AS IS", WITHOUT WARRANTY OF ANY KIND, EXPRESS OR
IMPLIED, INCLUDING BUT NOT LIMITED TO THE WARRANTIES OF MERCHANTABILITY,
FITNESS FOR A PARTICULAR PURPOSE AND NONINFRINGEMENT. IN NO EVENT SHALL THE
AUTHORS OR COPYRIGHT HOLDERS BE LIABLE FOR ANY CLAIM, DAMAGES OR OTHER
LIABILITY, WHETHER IN AN ACTION OF CONTRACT, TORT OR OTHERWISE, ARISING FROM,
OUT OF OR IN CONNECTION WITH THE SOFTWARE OR THE USE OR OTHER DEALINGS IN THE
SOFTWARE.
*/

// Simple remote sensor for HVAC, with OLED display, AM2320 and PIR sensor or button
// This uses HTTP GET to send temp/rh

// Build with Arduino IDE 1.8.9, esp8266 SDK 2.5.0, 1MB (FS:64KB) (SPIFFS)

// Uncomment if using a direct OLED display
//#define USE_OLED

//uncomment to enable Arduino IDE Over The Air update code
#define OTA_ENABLE

#include <Wire.h>
#ifdef USE_OLED
#include <ssd1306_i2c.h> // https://github.com/CuriousTech/WiFi_Doorbell/tree/master/Libraries/ssd1306_i2c
#endif

#include <EEPROM.h>
#include <ESP8266mDNS.h>
#include <ESPAsyncWebServer.h> // https://github.com/me-no-dev/ESPAsyncWebServer
#include <TimeLib.h> // http://www.pjrc.com/teensy/td_libs_Time.html
#include <UdpTime.h> // https://github.com/CuriousTech/ESP07_WiFiGarageDoor/tree/master/libraries/UdpTime
#include "eeMem.h"
#include <JsonParse.h> // https://github.com/CuriousTech/ESP8266-HVAC/tree/master/Libraries/JsonParse
#include <JsonClient.h> // https://github.com/CuriousTech/ESP8266-HVAC/tree/master/Libraries/JsonClient
#ifdef OTA_ENABLE
#include <FS.h>
#include <ArduinoOTA.h>
#endif
#include <FS.h>
#include <SPIFFSEditor.h>
#include "pages.h"
#include "jsonstring.h"
#include "TempArray.h"

// Uncomment only one
#include "tuya.h"  // Uncomment device in tuya.cpp
//#include "BasicSensor.h"

int serverPort = 80;

enum reportReason
{
  Reason_Setup,
  Reason_Status,
  Reason_Alert,
  Reason_Motion,
};

IPAddress lastIP;
IPAddress verifiedIP;
int nWrongPass;

uint32_t sleepTimer = 60; // seconds delay after startup to enter sleep (Note: even if no AP found)
int8_t nWsConnected;

AsyncWebServer server( serverPort );
AsyncWebSocket ws("/ws"); // access at ws://[esp ip]/ws
int WsClientID;

void jsonCallback(int16_t iName, int iValue, char *psValue);
JsonParse jsonParse(jsonCallback);
void jsonPushCallback(int16_t iEvent, uint16_t iName, int iValue, char *psValue);
JsonClient jsonPush(jsonPushCallback);

UdpTime utime;

eeMem ee;

bool bPIRTrigger;
uint16_t displayTimer;

#ifdef TUYA_H
TuyaInterface sensor;
#else
BasicInterface sensor;
#endif

#ifdef USE_OLED
SSD1306 display(0x3c, 5, 4); // Initialize the oled display for address 0x3c, sda=5, sdc=4
#endif

bool bConfigDone = false;
bool bStarted = false;
uint32_t connectTimer;

TempArray temps;

String settingsJson()
{
  jsonString js("settings");

  js.Var("tz",  ee.tz);
  js.Var("name", ee.szName);
  js.Var("to", ee.time_off );
  js.Var("srate", ee.sendRate);
  js.Var("lrate", ee.logRate);
  js.Var("sleep", ee.sleep);
  js.Var("pri", ee.e.PriEn);
  js.Var("o", ee.e.bEnableOLED);
  js.Var("l1", sensor.m_bLED[0]);
  js.Var("l2", sensor.m_bLED[1]);
  js.Var("pir", ee.e.bPIR);
  js.Var("pirpin", ee.pirPin);
  js.Var("prisec", ee.priSecs);
  js.Var("ch", ee.e.bCall);
  js.Var("ID", ee.sensorID);
  js.Var("cf", sensor.m_bCF);
  js.Var("df", sensor.m_dataFlags);
  js.Var("si", temps.m_bSilence);
  js.Var("wt", ee.weight);
  return js.Close();
}

String dataJson()
{
  jsonString js("state");

  js.Var("t", (uint32_t)now() - ( (ee.tz + utime.getDST() ) * 3600) );
  js.Var("df", sensor.m_dataFlags);
  js.Var("temp", String( (float)sensor.m_values[DE_TEMP] / 10, 1 ) );
  js.Var("rh", String((float)sensor.m_values[DE_RH] / 10, 1) );
  js.Var("st", sleepTimer);
  int sig = WiFi.RSSI();
  sensor.setSignal(sig);
  js.Var("rssi", sig);

  if(sensor.m_dataFlags & DF_CO2 )
    js.Var("co2", sensor.m_values[DE_CO2] );
  if(sensor.m_dataFlags & DF_CH2O )
    js.Var("ch2o", sensor.m_values[ DE_CH2O ] );
  if(sensor.m_dataFlags & DF_VOC )
    js.Var("voc", sensor.m_values[ DE_VOC ] );
  
  return js.Close();
}

void displayStart()
{
  if(ee.e.bEnableOLED == false && displayTimer == 0)
  {
#ifdef USE_OLED
    display.init();
#endif
  }
  displayTimer = 30;
}

const char *jsonList1[] = {
  "key",
  "name",
  "reset",
  "tempOffset",
  "oled",
  "TZ",
  "TO",
  "srate",
  "lrate", // 10
  "pir",
  "pri",
  "prisec",
  "led1",
  "led2",
  "cf",
  "ch",
  "hostip",
  "hist",
  "ID", // 20
  "sleep",
  "pirpin",
  "alertidx",
  "alertlevel",
  "silence",
  "rhOffset",
  "wt",
  NULL
};

void parseParams(AsyncWebServerRequest *request)
{
  if(nWrongPass && request->client()->remoteIP() != lastIP)  // if different IP drop it down
    nWrongPass = 10;
  lastIP = request->client()->remoteIP();

  for ( uint8_t i = 0; i < request->params(); i++ )
  {
    AsyncWebParameter* p = request->getParam(i);
    String s = request->urlDecode(p->value());

    uint8_t idx;
    for(idx = 0; jsonList1[idx]; idx++)
      if( p->name().equals(jsonList1[idx]) )
        break;
    if(jsonList1[idx])
    {
      int iValue = s.toInt();
      if(s == "true") iValue = 1;
      jsonCallback(idx, iValue, (char *)s.c_str());
    }
  }
}

bool bKeyGood;
bool bDataMode;

void jsonCallback(int16_t iName, int iValue, char *psValue)
{
  if(bKeyGood == false && iName != 0 && iName != 17 ) // allow hist
    return;  // only allow key set
  static int alertIdx;

  switch(iName)
  {
    case 0: // key
      if(!strcmp(psValue, ee.szControlPassword)) // first item must be key
      {
        bKeyGood = true;
        verifiedIP = lastIP;
      }
      break;
    case 1: // device name
      if(!strlen(psValue))
        break;
      strncpy(ee.szName, psValue, sizeof(ee.szName));
      ee.update();
      delay(1000);
      ESP.reset();
      break;
    case 2: // reset
      ee.update();
      delay(1000);
      ESP.reset();
      break;
    case 3: // tempOffset
      ee.tempCal = constrain(iValue, -80, 80);
      break;
    case 4: // OLED
      ee.e.bEnableOLED = iValue;
      break;
    case 5: // TZ
      ee.tz = iValue;
      break;
    case 6: // TO
      ee.time_off = iValue;
      break;
    case 7: // srate
      ee.sendRate = iValue;
      break;
    case 8: // lrate
      ee.logRate = iValue;
      break;
    case 9: // pir
      ee.e.bPIR = iValue;
      break;
    case 10: // pri
      ee.e.PriEn = iValue;
      break;
    case 11: // prisec
      ee.priSecs = iValue;
      break;
    case 12: // led1
      sensor.setLED(0, iValue ? true:false);
      break;
    case 13: // led2
      sensor.setLED(1, iValue ? true:false);
      break;
    case 14: // cf
      sensor.setCF(iValue ? true:false);
      break;
    case 15: // ch
      ee.e.bCall = iValue;
      if(iValue) CallHost(Reason_Setup, ""); // test
      break;
    case 16: // hostip
      ee.hostPort = 80;
      ee.hostIP[0] = lastIP[0];
      ee.hostIP[1] = lastIP[1];
      ee.hostIP[2] = lastIP[2];
      ee.hostIP[3] = lastIP[3];
      ee.e.bCall = 1;
      CallHost(Reason_Setup, ""); // test
      break;
    case 17: // hist
      temps.historyDump(true, ws, WsClientID);
      break;
    case 18:
      ee.sensorID = iValue;
      break;
    case 19:
      ee.sleep = iValue;
      break;
    case 20:
      ee.pirPin = iValue;
      break;
    case 21:
      alertIdx = constrain(iValue, 0, 15);
      break;
    case 22: // set alertidx first
      ee.wAlertLevel[alertIdx] = iValue;
      break;
    case 23:
      temps.m_bSilence = iValue ? true:false;
      break;
    case 24:
      ee.rhCal = iValue;
      break;
    case 25: // wt
      ee.weight = constrain(iValue, 1, 7);
      break;
  }
}

// Time in hh:mm[:ss][AM/PM]
String timeFmt(bool do_sec, bool do_M)
{
  String r = "";
  if(hourFormat12() < 10) r = " ";
  r += hourFormat12();
  r += ":";
  if(minute() < 10) r += "0";
  r += minute();
  if(do_sec)
  {
    r += ":";
    if(second() < 10) r += "0";
    r += second();
    r += " ";
  }
  if(do_M)
  {
      r += isPM() ? "PM":"AM";
  }
  return r;
}

const char *jsonListPush[] = { "",
  "time", // 0
  "ppkw",
  NULL
};

void jsonPushCallback(int16_t iEvent, uint16_t iName, int iValue, char *psValue)
{
  static uint8_t failCnt;

  switch(iEvent)
  {
    case -1: // status
      if(iName >= JC_TIMEOUT)
      {
        if(++failCnt > 5)
          ESP.restart();
      }
      else failCnt = 0;
      break;
    case 0: // time
      switch(iName)
      {
        case 0: // time
          setTime(iValue + (ee.tz * 3600));
          utime.DST();
          setTime(iValue + ((ee.tz + utime.getDST()) * 3600));
          temps.m_bValidDate = true;
          break;
      }
      break;
  }
}

struct cQ
{
  IPAddress ip;
  String sUri;
  uint16_t port;
};
#define CQ_CNT 8
cQ queue[CQ_CNT];
uint8_t qI;

void checkQueue()
{
  if(WiFi.status() != WL_CONNECTED)
    return;

  int idx;
  for(idx = 0; idx < CQ_CNT; idx++)
  {
    if(queue[idx].port)
      break;
  }
  if(idx == CQ_CNT || queue[idx].port == 0) // nothing to do
    return;

  if( jsonPush.begin(queue[idx].ip, queue[idx].sUri.c_str(), queue[idx].port, false, false, NULL, NULL, 1) )
  {
    jsonPush.addList(jsonListPush);
    queue[idx].port = 0;
  }
}

bool callQueue(IPAddress ip, String sUri, uint16_t port)
{
  int idx;
  for(idx = 0; idx < CQ_CNT; idx++)
  {
    if(queue[idx].port == 0)
      break;
  }
  if(idx == CQ_CNT) // nothing to do
  {
    jsonString js("print");
    js.Var("text", "Q full");
    WsSend(js.Close());
    return false;
  }

  queue[idx].ip = ip;
  queue[idx].sUri = sUri;
  queue[idx].port = port;

  return true;
}

void CallHost(reportReason r, String sStr)
{
  if(WiFi.status() != WL_CONNECTED || ee.hostIP[0] == 0 || ee.e.bCall == false)
    return;

  String sUri = "/wifi?name=\"";
  sUri += ee.szName;
  sUri += "\"&reason=";

  switch(r)
  {
    case Reason_Setup:
      sUri += "setup&port="; sUri += serverPort;
      break;
    case Reason_Status:
      if(sensor.m_values[DE_TEMP] == 0)
        return;

      sUri += "status&temp="; sUri += String( (float)sensor.m_values[DE_TEMP]/10 , 1);
      sUri += "&rh="; sUri += String( (float)sensor.m_values[DE_RH]/10 , 1);
      break;
    case Reason_Alert:
      sUri += "alert&value=\"";
      sUri += sStr;
      sUri += "\"";
      break;
    case Reason_Motion:
      sUri += "motion";
      break;
  }

  IPAddress ip(ee.hostIP);
  callQueue(ip, sUri.c_str(), ee.hostPort);
}

void sendTemp()
{
  if(WiFi.status() != WL_CONNECTED || ee.hvacIP[0] == 0) // not set
    return;

  uint8_t sentWt;
  String sUri = String("/s?key=");
  sUri += ee.szControlPassword;
  sUri += "&rmtname="; sUri += ee.sensorID;
  sUri += "&rmttemp=";
  sUri += sensor.m_values[DE_TEMP];
  sUri += (ee.e.bCF) ? "F" : "C";
  sUri += "&rmtrh="; sUri += sensor.m_values[DE_RH];
  if(sentWt != ee.weight)
  {
    sentWt = ee.weight;
    sUri += "&rmtwt="; sUri += ee.weight;
  }

  if(ee.e.bPIR && bPIRTrigger )
  {
    if(ee.priSecs)
      sUri += "&rmtto="; sUri += ee.priSecs;
    bPIRTrigger = false;
  }

  IPAddress ip(ee.hvacIP);
  callQueue(ip, sUri, 80);
}

uint16_t stateTimer = 10;

void sendState()
{
  if(nWsConnected)
    ws.textAll(dataJson());
  stateTimer = ee.sendRate;
}

void findHVAC() // This seems to show only 6 at a time
{
  int n = MDNS.queryService("iot", "tcp");
  int d;
  for(int i = 0; i < n; ++i)
  {
    char szName[38];
    MDNS.hostname(i).toCharArray(szName, sizeof(szName));
    strtok(szName, "."); // remove .local

    if(!strcmp(szName, "HVAC"))
    {
      ee.hvacIP[0] = MDNS.IP(i)[0]; // update IP
      ee.hvacIP[1] = MDNS.IP(i)[1];
      ee.hvacIP[2] = MDNS.IP(i)[2];
      ee.hvacIP[3] = MDNS.IP(i)[3];
      break;
    }
  }
}

void onWsEvent(AsyncWebSocket * server, AsyncWebSocketClient * client, AwsEventType type, void * arg, uint8_t *data, size_t len)
{  //Handle WebSocket event
  static bool bRestarted = true;
  String s;

  switch(type)
  {
    case WS_EVT_CONNECT:      //client connected
      if(bRestarted)
      {
        bRestarted = false;
//        client->text("alert;Restarted");
      }
      client->keepAlivePeriod(50);
      client->text( settingsJson() );
      client->text( dataJson() );
      client->ping();
      nWsConnected++;
      break;
    case WS_EVT_DISCONNECT:    //client disconnected
      bDataMode = false; // turn off numeric display and frequent updates
      if(nWsConnected)
        nWsConnected--;
      break;
    case WS_EVT_ERROR:    //error was received from the other end
      break;
    case WS_EVT_PONG:    //pong message was received (in response to a ping request maybe)
      break;
    case WS_EVT_DATA:  //data packet
      AwsFrameInfo * info = (AwsFrameInfo*)arg;
      if(info->final && info->index == 0 && info->len == len){
        //the whole message is in a single frame and we got all of it's data
        if(info->opcode == WS_TEXT){
          data[len] = 0;

          uint32_t ip = client->remoteIP();
          WsClientID = client->id();

          bKeyGood = (ip && verifiedIP == ip) ? true:false; // if this IP sent a good key, no need for more
          jsonParse.process((char *)data);
          if(bKeyGood)
            verifiedIP = ip;
        }
      }
      break;
  }
}

void WsSend(String s)
{
  ws.textAll(s);
}

void alert(String txt)
{
  jsonString js("alert");
  js.Var("text", txt);
  ws.textAll(js.Close());
}

void setup()
{
  ee.init();
  sensor.init(ee.e.bCF);

  // initialize dispaly
#ifdef USE_OLED
  display.init();
//  display.flipScreenVertically();
  display.clear();
  display.display();
#endif

  WiFi.hostname(ee.szName);
  WiFi.mode(WIFI_STA);

  if ( ee.szSSID[0] )
  {
    WiFi.begin(ee.szSSID, ee.szSSIDPassword);
    WiFi.setHostname(ee.szName);
    bConfigDone = true;
  }
  else
  {
    Serial.println("No SSID. Waiting for EspTouch.");
    WiFi.beginSmartConfig();
  }
  connectTimer = now();

  SPIFFS.begin();
  server.addHandler(new SPIFFSEditor("admin", ee.szControlPassword));

  // attach AsyncWebSocket
  ws.onEvent(onWsEvent);
  server.addHandler(&ws);

  server.on( "/", HTTP_GET | HTTP_POST, [](AsyncWebServerRequest *request){
    parseParams(request);
    bDataMode = true;
//  request->send(SPIFFS, "/index.html");
    request->send_P(200, "text/html", page_index);
  });
  server.on( "/s", HTTP_GET | HTTP_POST, [](AsyncWebServerRequest *request){
    parseParams(request);

    String page = "{\"ip\": \"";
    page += WiFi.localIP().toString();
    page += ":";
    page += serverPort;
    page += "\"}";
    request->send( 200, "text/json", page );
  });
  server.on( "/json", HTTP_GET | HTTP_POST, [](AsyncWebServerRequest *request){
    parseParams(request);
    request->send( 200, "text/json", settingsJson() );
  });
  server.on("/heap", HTTP_GET, [](AsyncWebServerRequest *request){
    request->send(200, "text/plain", String(ESP.getFreeHeap()));
  });
  server.on("/favicon.ico", HTTP_GET, [](AsyncWebServerRequest *request){
    AsyncWebServerResponse *response = request->beginResponse_P(200, "image/x-icon", favicon, sizeof(favicon));
    response->addHeader("Content-Encoding", "gzip");
    request->send(response);
  });

  server.onNotFound([](AsyncWebServerRequest *request){
    request->send(404);
  });

  server.onFileUpload([](AsyncWebServerRequest *request, String filename, size_t index, uint8_t *data, size_t len, bool final){
  });
  server.onRequestBody([](AsyncWebServerRequest *request, uint8_t *data, size_t len, size_t index, size_t total){
  });

  server.begin();

#ifdef OTA_ENABLE
  ArduinoOTA.setHostname(ee.szName);
  ArduinoOTA.begin();
  ArduinoOTA.onStart([]() {
    ee.update();
    sensor.setLED(0, false); // set it all to off
    temps.saveData();
    SPIFFS.end();
    alert("OTA Update Started");
    ws.closeAll();
  });
#endif

  jsonParse.setList(jsonList1);
  sensor.setLED(0, false);
  if(ee.sendRate == 0) ee.sendRate = 60;
  sleepTimer = ee.sleep;
  temps.init(sensor.m_dataFlags);
  if(ee.weight == 0)
    ee.weight = 1;
  if(ee.pirPin)
    pinMode(ee.pirPin, INPUT);
}

void loop()
{
  static uint8_t hour_save, sec_save;
  static uint8_t cnt = 0;
  bool bNew;

  MDNS.update();
#ifdef OTA_ENABLE
  ArduinoOTA.handle();
#endif
  if(WiFi.status() == WL_CONNECTED && ee.e.bUseTime)
  {
    if(utime.check(ee.tz))
      temps.m_bValidDate = true;
  }

  if(ee.pirPin)
  {
    static bool last_pir;
    if(digitalRead(ee.pirPin) != last_pir)
    {
      last_pir = digitalRead(ee.pirPin);
      if(last_pir)
      {
        CallHost(Reason_Motion, "");
        if(ee.e.bPIR && bPIRTrigger)
          sendTemp();
        jsonString js("print");
        js.Var("text", "Motion");
        WsSend(js.Close());
      }
    }
  }

  static int htimer = 10;
  if(--htimer == 0)
  {
    temps.historyDump(false, ws, WsClientID);
    htimer = 30;
  }

  if(int err = sensor.service(ee.tempCal, ee.rhCal))
  {
    String s = "Sensor error ";
    s += err;
    alert(s);
  }

  checkQueue();

  if(sec_save != second()) // only do stuff once per second (loop is maybe 20-30 Hz)
  {
    sec_save = second();

    if(!bConfigDone)
    {
      if( WiFi.smartConfigDone())
      {
        Serial.println("SmartConfig set");
        bConfigDone = true;
        connectTimer = now();
      }
    }
    if(bConfigDone)
    {
      if(WiFi.status() == WL_CONNECTED)
      {
        if(!bStarted)
        {
          Serial.println("WiFi Connected");
          MDNS.begin( ee.szName );
          bStarted = true;
          MDNS.addService("iot", "tcp", serverPort);
          WiFi.SSID().toCharArray(ee.szSSID, sizeof(ee.szSSID)); // Get the SSID from SmartConfig or last used
          WiFi.psk().toCharArray(ee.szSSIDPassword, sizeof(ee.szSSIDPassword) );
          ee.update();

          if(ee.e.bUseTime) // Host and HVAC return current time
            utime.start();
          findHVAC();
          CallHost(Reason_Setup, "");
        }
      }
      else if(now() - connectTimer > 10) // failed to connect for some reason
      {
        Serial.println("Connect failed. Starting SmartConfig");
        connectTimer = now();
        ee.szSSID[0] = 0;
        WiFi.mode(WIFI_AP_STA);
        WiFi.beginSmartConfig();
        bConfigDone = false;
        bStarted = false;
      }
    }

    if(hour_save != hour())
    {
      hour_save = hour();
      if((hour_save&1) == 0)
        CallHost(Reason_Setup, "");
      if(hour_save == 2 && ee.e.bUseTime)
        utime.start(); // update time daily at DST change
      ee.update(); // update EEPROM if needed while we're at it (give user time to make many adjustments)
    }

    if(nWrongPass)
      nWrongPass--;

    if(displayTimer) // temp display on thing
      displayTimer--;

    if(sleepTimer && nWsConnected == 0 && WiFi.status() == WL_CONNECTED) // don't sleep until all ws connections are closed
    {
      if(--sleepTimer == 0)
      {
        if(ee.time_off)
        {
          uint32_t us = ee.time_off * 60022000;  // minutes to us calibrated
#ifdef USE_OLED
          display.displayOff();
#endif
          ESP.deepSleep(us, WAKE_RF_DEFAULT);
        }
      }
    }

    if(--stateTimer == 0 || sensor.m_bUpdated) // a 60 second keepAlive
    {
      if(sensor.m_bUpdated)
        temps.update(sensor.m_values);
      sensor.m_bUpdated = false;
      sendState();
    }

    static uint8_t timer = 5;
    if(--timer == 0)
    {
      timer = 30;
      if(sensor.m_values[DE_RH])
        CallHost(Reason_Status, "");
    }

    static uint8_t sendTimer = 20;
    if(--sendTimer == 0)
    {
      sendTimer = ee.sendRate;
      sendTemp();
    }
    static uint8_t addTimer = 10;
    if(--addTimer == 0)
    {
      addTimer = ee.logRate;
      temps.add( (uint32_t)now() - ( (ee.tz + utime.getDST() ) * 3600), ws, WsClientID);
    }
  }

  if(WiFi.status() != WL_CONNECTED)
  {
    delay(40);
    sensor.setLED(0, !sensor.m_bLED[0] );
    return;
  }/*
  else if(wifi.state() == ws_connecting)
  {
    sensor.setLED(0, true);
    delay(8);
    sensor.setLED(0, false);
    return;
  }*/

#ifdef USE_OLED
  static bool bClear;
  bool bDraw = (ee.e.bEnableOLED || displayTimer || bDataMode);
  if(bDraw == false && bClear)
    return;

  // draw the screen here
  display.clear();
  if(bDraw)
  {
    String s = timeFmt(true, true);
    s += "  ";
    s += dayShortStr(weekday());
    s += " ";
    s += String(day());
    s += " ";
    s += monthShortStr(month());
    s += "  ";

    Scroller(s);

    display.drawPropString(2, 47, String((float)temp/10, 1) + "]");
    display.drawPropString(64, 47, String((float)rh/10, 1) + "%");
    bClear = false;
  }
  else
    bClear = true;
  display.display();
#endif
}

// Text scroller optimized for very long lines
#ifdef USE_OLED
void Scroller(String s)
{
  static int16_t ind = 0;
  static char last = 0;
  static int16_t x = 0;

  if(last != s.charAt(0)) // reset if content changed
  {
    x = 0;
    ind = 0;
  }
  last = s.charAt(0);
  int len = s.length(); // get length before overlap added
  s += s.substring(0, 18); // add ~screen width overlap
  int w = display.propCharWidth(s.charAt(ind)); // first char for measure
  String sPart = s.substring(ind, ind + 18);
  display.drawPropString(x, 0, sPart );

  if( --x <= -(w))
  {
    x = 0;
    if(++ind >= len) // reset at last char
      ind = 0;
  }
}
#endif

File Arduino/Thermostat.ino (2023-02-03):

/**The MIT License (MIT)

Copyright (c) 2016 by Greg Cunningham, CuriousTech

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
THE SOFTWARE IS PROVIDED "AS IS", WITHOUT WARRANTY OF ANY KIND, EXPRESS OR
IMPLIED, INCLUDING BUT NOT LIMITED TO THE WARRANTIES OF MERCHANTABILITY,
FITNESS FOR A PARTICULAR PURPOSE AND NONINFRINGEMENT. IN NO EVENT SHALL THE
AUTHORS OR COPYRIGHT HOLDERS BE LIABLE FOR ANY CLAIM, DAMAGES OR OTHER
LIABILITY, WHETHER IN AN ACTION OF CONTRACT, TORT OR OTHERWISE, ARISING FROM,
OUT OF OR IN CONNECTION WITH THE SOFTWARE OR THE USE OR OTHER DEALINGS IN THE
SOFTWARE.
*/

// Build with Arduino IDE 1.8.19
//  ESP8266 (3.1.1)  1MB (FS:64Kb)
//  ESP32: (2.0.6) ESP Dev Module, 115200 baud, 80MHz (WiFi/BT) or any speed, QIO, Default 4MB with spiffs
// For remote unit, uncomment #define REMOTE in HVAC.h

#include <ESPAsyncWebServer.h> // https://github.com/me-no-dev/ESPAsyncWebServer
#include <TimeLib.h> // http://www.pjrc.com/teensy/td_libs_Time.html
#include <UdpTime.h> // https://github.com/CuriousTech/ESP07_WiFiGarageDoor/tree/master/libraries/UdpTime
#include "HVAC.h"
#include "Encoder.h"
#include "WebHandler.h"
#include "display.h"
#include <Wire.h>
#include "eeMem.h"
#include "RunningMedian.h"

// ESP8266 uncomment to swap Serial's pins to 15(TX) and 13(RX) that don't interfere with booting
//#define SER_SWAP https://github.com/esp8266/Arduino/blob/master/doc/reference.md

// Uncomment only one of these
#include <SHT21.h> // //Libraries/SHT21
//#include <DHT.h>  // http://www.github.com/markruys/arduino-DHT
//#include <DallasTemperature.h> //DallasTemperature from library mamanger
//#include <AM2320.h> // //Libraries/AM2320

//----- Pin Configuration - See HVAC.h for the rest -
#ifdef ESP32
#define SDA      21
#define SCL      22
#define ENC_A    16
#define ENC_B    4
#else // ESP8266 pins
#define SDA      2
#define SCL      13
#define ENC_A    5  // Encoder is on GPIO4 and 5
#define ENC_B    4
#endif
//------------------------

Display display;
eeMem ee;

HVAC hvac;

RunningMedian<int16_t,25> tempMedian; //median of 25 samples

#ifdef SHT21_H
SHT21 sht(SDA, SCL, 4);
#endif
#ifdef dht_h
DHT dht;
#endif
#ifdef DallasTemperature_h
const int ds18Resolution = 12;
DeviceAddress ds18addr = { 0x28, 0xC1, 0x02, 0x64, 0x04, 0x00, 0x00, 0x35 };
unsigned int ds18delay;
unsigned long ds18lastreq = 1; //zero is special
const unsigned int ds18reqdelay = 5000; //request every 5 seconds
unsigned long ds18reqlastreq;
OneWire oneWire(2); //pin 2
DallasTemperature ds18(&oneWire);
#endif
#ifdef AM2303_H
AM2320 am;
#endif

UdpTime uTime;

Encoder rot(ENC_B, ENC_A);

extern void WsSend(String s);

bool EncoderCheck()
{
  if(ee.b.bLock) return false;

  int r = rot.poll();

  if(r == 0)  // no change
    return false;

  display.screen(true); // ensure page is thermostat

  int8_t m = (display.m_adjustMode < 2) ? Mode_Cool : Mode_Heat; // lower 2 are cool
  int8_t hilo = (display.m_adjustMode ^ 1) & 1; // hi or low of set
  int16_t t = hvac.getSetTemp(m, hilo ); // 

  t += r; // inc/dec by any amount

  hvac.setTemp(m, t, hilo);

  if(hvac.m_bLink) // adjust both high and low
  {
    t = hvac.getSetTemp(m, hilo^1 ) + r; // adjust opposite hi/lo the same
    hvac.setTemp(m, t, hilo^1);
  }

  display.updateTemps();
  return true;
}

void setup()
{
  Serial.begin(115200);  // Nextion must be set with bauds=115200
#ifdef SER_SWAP
  Serial.swap(); //swap to gpio 15/13
#endif
  ee.init();
  hvac.init();
  display.init();
  startServer();

#ifdef SHT21_H
  sht.init();
#endif
#ifdef dht_h
  dht.setup(SCL, DHT::DHT22);
#endif
#ifdef DallasTemperature_h
  ds18.setResolution(ds18addr, ds18Resolution);
  ds18.setWaitForConversion(false); //this enables asyncronous calls
  ds18.requestTemperatures(); //fire off the first request
  ds18lastreq = millis();
  ds18delay = 750 / (1 << (12 - ds18Resolution)); //delay based on resolution
#endif
#ifdef AM2303_H
  am.begin(SDA, SCL);
#endif
}

void loop()
{
  static uint8_t hour_save, min_save = 255, sec_save;
  static int8_t lastSec;
  static int8_t lastHour;
  static int8_t lastDay = -1;

  while( EncoderCheck() );
  display.checkNextion();  // check for touch, etc.
  if(uTime.check(ee.tz))
  {
    hvac.m_DST = uTime.getDST();
    if(lastDay == -1)
      lastDay = day() - 1;
  }
  handleServer(); // handles mDNS, web
#ifdef SHT21_H
  if(sht.service())
  {
    tempMedian.add((ee.b.bCelcius ? sht.getTemperatureC():sht.getTemperatureF()) * 10);
    float temp;
    if (tempMedian.getAverage(2, temp) == tempMedian.OK) {
      hvac.updateIndoorTemp( temp, sht.getRh() * 10 );
    }
  }
#endif
#ifdef DallasTemperature_h
  if(ds18lastreq > 0 && millis() - ds18lastreq >= ds18delay) { //new temp is ready
    tempMedian.add((ee.b.bCelcius ? ds18.getTempC(ds18addr):ds18.getTempF(ds18addr)) );
    ds18lastreq = 0; //prevents this block from firing repeatedly
    float temp;
    if (tempMedian.getAverage(temp) == tempMedian.OK) {
      hvac.updateIndoorTemp( temp * 10, 500); //fake 50%
    }
  }

  if(millis() - ds18reqlastreq >= ds18reqdelay) {
    ds18.requestTemperatures(); 
    ds18lastreq = millis();
    ds18reqlastreq = ds18lastreq;
  }
#endif
  if(sec_save != second()) // only do stuff once per second
  {
    sec_save = second();
    if(secondsServer()) // once per second stuff, returns true once on connect
      uTime.start();
    display.oneSec();
    hvac.service();   // all HVAC code

#ifdef dht_h
    static uint8_t read_delay = 2;
    if(--read_delay == 0)
    {
      float temp;
      if(ee.bCelcius)
        temp = dht.getTemperature() * 10;
      else
        temp = dht.toFahrenheit(dht.getTemperature()) * 10;

      if(dht.getStatus() == DHT::ERROR_NONE)
      {
        tempMedian.add(temp);
        if (tempMedian.getAverage(2, temp) == tempMedian.OK) {
          hvac.updateIndoorTemp( temp, dht.getHumidity() * 10);
        }
      }
      read_delay = 5; // update every 5 seconds
    }
#endif
#ifdef AM2303_H
    static uint8_t read_delay = 2;
    if(--read_delay == 0)
    {
      float temp;
      float rh;
      if(am.measure(temp, rh))
      {
        if(!ee.b.bCelcius)
          temp = temp * 9 / 5 + 32;
        tempMedian.add(temp * 10);
        if (tempMedian.getAverage(2, temp) == tempMedian.OK) {
          hvac.updateIndoorTemp( temp, rh * 10 );
        }
      }
      read_delay = 5; // update every 5 seconds
    }
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

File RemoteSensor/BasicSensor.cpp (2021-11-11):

// Class for AM2320 temp and humidity

#include "BasicSensor.h"
#include <TimeLib.h> // http://www.pjrc.com/teensy/td_libs_Time.html

#define ESP_LED  2  // low turns on ESP blue LED
#define CF_BTN   13  // C/F button

extern void WsSend(String s);

void BasicInterface::init(bool bCF)
{
  pinMode(ESP_LED, OUTPUT);
  digitalWrite(ESP_LED, LOW);
  m_am.begin(5, 4);
  m_bCF = bCF;
}

int BasicInterface::service(int8_t tcal, int8_t rhcal)
{
  static uint8_t lastSec;

  if(second() == lastSec)
    return 0;

  lastSec = second();

  if((lastSec % 5) == 0)
  {
    float ftemp, frh;
    if(m_am.measure(ftemp, frh))
    {
      m_status = 0;
      
      if(m_bCF)
        ftemp = ( 1.8 * ftemp + 32.0) * 10;
      else
        ftemp *= 10;
      ftemp += tcal;
      m_tempMedian[0].add( ftemp);
      m_tempMedian[0].getAverage(2, ftemp);
      m_tempMedian[1].add(frh * 10);
      m_tempMedian[1].getAverage(2, frh);
      if(m_values[DE_TEMP] != (uint16_t)ftemp || m_values[DE_RH] != (uint16_t)frh)
        m_bUpdated = true;
      m_values[DE_TEMP] = ftemp;
      m_values[DE_RH] = frh + rhcal;
    }
    else
    {
      m_status = 1;
    }
  }

  static bool bBtn = true;
  if( digitalRead(CF_BTN) != bBtn )
  {
    bBtn = digitalRead(CF_BTN);
    if( bBtn ) // release
      setCF( !m_bCF );
  }
  return m_status;
}

void BasicInterface::setCF(bool f)
{
  m_bCF = f;
}

int BasicInterface::status()
{
  return m_status;
}

void BasicInterface::setLED(uint8_t no, bool bOn)
{
  m_bLED[0] = bOn;
  digitalWrite(ESP_LED, !bOn);   // No external LED
}

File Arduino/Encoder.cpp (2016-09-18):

#include "Encoder.h"

Encoder::Encoder(int8_t aPin, int8_t bPin, void (*callback)())
{
  pinMode(aPin, INPUT_PULLUP);
  pinMode(bPin, INPUT_PULLUP);

  m_aPin = aPin;
  m_bPin = bPin;

  m_lastA = digitalRead(aPin);
  attachInterrupt(aPin, callback, FALLING);
}

Encoder::Encoder(int8_t aPin, int8_t bPin)
{
  pinMode(aPin, INPUT_PULLUP);
  pinMode(bPin, INPUT_PULLUP);

  m_aPin = aPin;
  m_bPin = bPin;

  m_lastA = digitalRead(aPin);
}

int Encoder::poll()
{
  int8_t A = digitalRead(m_aPin);

  m_dir = 0;

  if(!A && A != m_lastA)  // simulate falling edge of A
  {
    m_ticks ++;
    m_dir = digitalRead(m_bPin) ? -1 : 1;
  }

  m_lastA = A;
  return m_dir;
}

// get changes
int Encoder::read()
{
  if(m_ticks == 0)
    return 0;
  int n = m_dir * m_ticks;
  m_ticks = 0;
  return n;
}

// isr (falling edge of A)
void Encoder::isr()
{
  m_ticks++;
  m_dir = digitalRead(m_bPin) ? -1 : 1;
}

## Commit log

2016-04-29 Changed interval timer
2016-04-29 Remote timeout fix, and tabs
    [HVAC.cpp]
2016-05-01 Incomplete-local temp sensor not implemented
2016-05-02 Bug fix for SDK 2.2.0 update
    [WebHandler.cpp]
2016-05-11 Added R19 (optional)
    [Thermostat.brd]
2016-05-11 Bugfix. Reverse valve wasn't the one with PNP
    [HVAC.cpp]
2016-05-12 Added R20 before PNP
    [Thermostat.brd]
2016-05-17 Small temp update fixes
    [HVAC.cpp]
2016-05-20 Missing code in tempChange()
    [HVAC.cpp]
2016-05-27 added fan pre-cycle experiment
2016-05-27 Fan pre-cycle
2016-05-27 Fan pre-cycle experimental code
2016-05-27 optimized, added fan pre
2016-05-27 changed DHT lib, forecast fix
    [Thermostat.ino]
2016-05-29 local/remote temp display fix
    [HVAC.h]
2016-06-02 Fan precycle threshold stop
2016-06-06 Moved USB to top
    [Thermostat.brd]
2016-06-06 Mislabeled MCP1755 as MCP1801
    [Thermostat.sch]
2016-06-08 Introduced manual fan bug. Fixed.
    [HVAC.cpp]
2016-06-13 found missing switch break
    [HVAC.cpp]
2016-06-14 fan precycle bugfix
2016-06-15 r1 - better, but not perfect
    [Thermostat.brd]
2016-06-16 rmt switch command
2016-06-17 Broke the humid levels with constrain
    [HVAC.cpp]
2016-07-08 Added a lock button
2016-07-08 Switched to forecast for time
2016-08-12 Added reset, 3-way fan
2016-08-12 3-way fan mode
2016-08-12 Added total/filter reset, fan mode
    [WebHandler.cpp]
2016-08-13 Missed a cutoff for fan cycle
    [HVAC.cpp]
2016-08-29 Split web UI to 2 pages - correct file
    [WebHandler.cpp]
2016-09-10 Added timestamp, fan
2016-09-18 Encoder fix
    add option for no interrupt callback
    [Encoder.cpp]
2016-09-18 Encoder fix (#1)
    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
    [Encoder.cpp]
2016-09-18 Revert "Encoder fix (#1)"
    This reverts commit 74e6559e974f6c28643bbec9eb9b668e4b65f8b1.
    [Encoder.cpp]
2016-09-26 Copied RangeMedian to the other temp sensors
2016-09-26 Removed code from callback for stability
    [Thermostat.ino]
2016-10-08 Added WebSocket, chunked chart (buggy)
    [WebHandler.cpp]
2016-10-08 Switched to WebSockets
2016-10-09 Fixed remote switch
2016-10-09 Remote disconnect fix, delimiter change
    [WebHandler.cpp]
2016-10-19 Missing commands, merged for ease
    [WebHandler.cpp]
2016-10-28 log state/fan merge
2016-10-28 Switched to AsyncWebServer
2016-10-28 Split costs, fixed float overrun, dual thresholds
    [HVAC.cpp]
2016-11-14 fan on + heat compiler bug workaround
    [HVAC.cpp]
2017-01-14 Update for WiFiMaanger fix
    [WebHandler.cpp]
2017-02-22 forecast source switch
2017-03-15 Stuck DST here for now
    [HVAC.h]
2017-03-15 Fixed DST, adjustable forecast future test
    [HVAC.cpp]
2017-06-14 Changed set buttons to 1 save
2017-06-14 Changed set button to 1 save
2017-07-07 Fix for printfAll bug
    [WebHandler.cpp]
2017-09-01 Wrong month for total
    [Thermostat.ino]
2017-09-15 Preserve day costs current month
2017-09-21 Wheel for encoder. 38mm x 5mm
    [Encoder Wheel.stl]
2017-09-25 Lower profile, tighter fit
    [Encoder Wheel.stl]
2017-09-26 3D object of remote back
    [Remote back.stl]
2018-04-28 Slight button size change
2018-05-01 Replaced another printf
2018-06-21 Added temp up/down buttons
2018-06-21 Moved buttons
2018-06-21 Added up/down buttons for slim model
2018-07-10 Fixed larger chart history throughput
    [WebHandler.cpp]
2018-07-19 Model 2 case
    [BackM2.stl, FaceplateM2.stl, RmtBackM2.stl]
2018-07-20 Flush back Model 2 (thicker)
    [BackDeepM2.stl]
2018-08-02 Didn't the back capacitor hole
    [RmtBackM2.stl]
2018-08-03 Larger USB opening
    [RmtBackM2.stl]
2018-08-05 wire color comments
2019-06-08 Switched to port 80
2019-12-12 milti-remote sensor (incomplete)
2019-12-12 Swapped SCL/SDA on r1 board in 2018
    [Thermostat.ino]
2019-12-12 Corrected heat/cool threshold for display
2020-03-01 Model 2 case (open sensor)
    [BackM2.stl]
2020-04-07 Bugfix: 2 entry shift on forecast
    [WebHandler.cpp]
2020-04-24 Chart button moved
2021-02-04 Correct month data reset
    [Thermostat.ino]
2021-02-04 Correct month total reset
    [HVAC.cpp]
2021-02-04 1 byte shorter read
    [Nextion.cpp]
2021-02-06 Added fan circulate timer
2021-02-06 New fan settings
2021-02-06 Fan settings
2021-02-06 Fan timer
2021-02-06 Fan circulate timer
2021-02-15 New remote sensor handling
2021-02-15 Remote sensor handling
2021-02-15 Added array for sensors
2021-02-15 Sensor display/controls
2021-02-16 Auto heat threshold check missing in heat only
    [HVAC.cpp]
2021-03-21 Added ext sensors to chart
2021-03-21 sensor data for chart record
2021-03-21 Sensor data logging stuff
2021-03-21 Sensor data stuff
2021-03-21 Possible bugfix for overwriting Jan 1 log
    [Thermostat.ino]
2021-04-10 32 bit timers for no reason
2021-04-26 Fix for chart threshold
    [HVAC.cpp]
2021-05-25 Cast fix for new esp8266 sdk
    [WebHandler.cpp]
2021-05-25 Better sensor valid maintainer
2021-06-18 ESP32 compatible
2021-06-20 ON/OFF pin states
2021-06-25 New sensor switch method
2021-06-25 Error checked with all sensors, C/F, ESP32 compat
    [Thermostat.ino]
2021-06-25 New sensor flags
2021-06-25 C/F and sensor flag changes
2021-06-26 Sensor names in warnings
2021-07-17 rev 1. GPIO12 is connected to 1.3V LDO (r0 failed!)
    [Thermostat.brd, Thermostat.sch]
2021-07-17 Updated I/O pins for rev 1 ESP32
2021-08-05 Fix for ESP32 failing to open eeprom file before setup
2021-08-10 Worst mistake ever. I quit.
    [Thermostat.brd, Thermostat.sch]
2021-09-20 Changed sensor flags
2021-09-20 More sensor controls
2021-09-20 Added pri, avg, timer, C/F, PIR sensor
2021-09-21 Added OTA setHostname (correctly spelled)
    [WebHandler.cpp]
2021-09-28 Changed to PRI for remote switch. Avg is set in page
2021-10-02 Manager for dead sensors, rh averaging
2021-10-02 Added 2 tuya devices
2021-10-03 ESP32 fix
2021-10-03 ESP32 audio does work
2021-10-20 Internal sensor changes
2021-10-20 Moved internal sensor to sensor list
2021-11-11 Added calibration
2021-11-11 Forecast update timer added
2022-01-02 Changed sensor name
2022-01-02 Sensor error check changes
    [HVAC.cpp]
2022-03-08 simplified priority sensor
2022-05-14 Changed flags, added sensor weight
2022-05-14 Added sensor weight
2022-05-15 Added internal sensor weight
2022-06-04 Small fix for static weight
    [Sensor.ino]
2022-07-08 Fix for up to 7 external sensors
2022-07-08 Added sensor sort and moved remote name/ID to .h
2022-11-23 Sensor data packed
2023-01-26 Switched to SmartConnect/EspTouch app
2023-01-26 Switched to SmartConfig
2023-11-26 Missed a couple adjustments

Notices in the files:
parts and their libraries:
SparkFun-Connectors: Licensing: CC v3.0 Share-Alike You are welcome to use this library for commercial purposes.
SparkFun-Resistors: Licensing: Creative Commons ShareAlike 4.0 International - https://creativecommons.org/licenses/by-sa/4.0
